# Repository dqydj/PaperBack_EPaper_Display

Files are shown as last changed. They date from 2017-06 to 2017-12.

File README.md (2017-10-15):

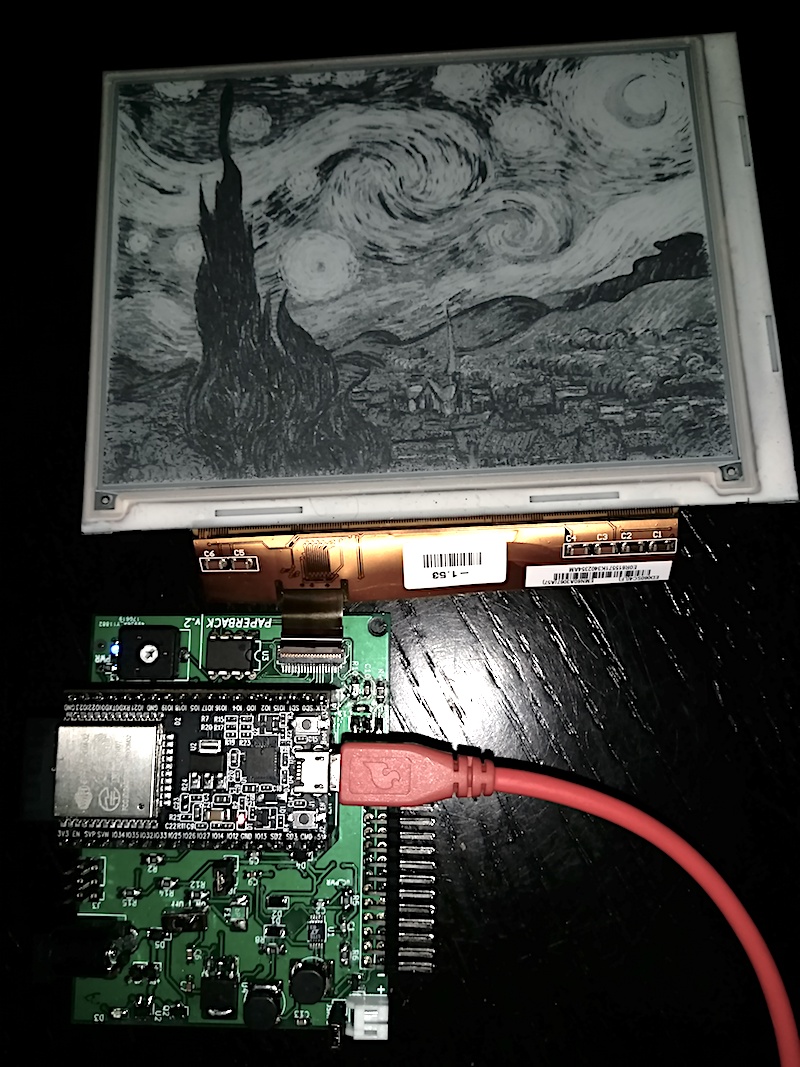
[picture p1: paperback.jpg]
Paperback Preview


# PaperBack EPaper Display

PaperBack is a modular, internet connected _*OR*_ VGA EPaper Display. It consists of a breakout board for a 39 pin ePaper display and an ESP32 in one mode. In the other, remove the ESP32 and attach a VGA Conversion board and use regular VGA input to drive the display!

PaperBack is an entry in the 2017 Hackaday Prize, you can see a more complete (and verbose!) [writeup here](https://hackaday.io/project/21607-paperback-desktop-e-paper-monitor).

## Hardware Overview

Currently, PaperBack works both driven by an ESP32 Development Board, or directly via VGA with the attached second PCB.

Hardware Overview:

* Espressif ESP32 Dev Board
* ED060SC4 // LB060S01 // LB060S04 6" ePaper Display
* 800x600 Resolution
* 16 Color (Greyscale) Support / 4-Bit Grey

## Software/Firmware Overview

Remember, choose one at a time! You can use the ESP32 breakout board with the ESP32 dev board, or remove the dev board and attach the VGA converter.

### VGA Driven

Unplug any ESP32 from the socket and attach both boards, then attach power (see below). When the board detects a signal it will start to refresh.

All firmware is in the /firmware_VGA/FPGA and /firmware_VGA/Microcontroller directories.

The user switches change color depth (read: shades of gray. 2 color is black & white.) and refresh speed:
Switch 3 (Furthest from Microcontroller)
Switch 2
Switch 1 (Closest to Microcontroller)

* On  On  On  - 16 color, ~10 seconds between frames
* On  On  Off - 16 color, ~5 seconds between frames
* On  Off On  - 4 color, ~10 seconds between frames
* On  Off Off - 4 color, ~5 seconds between frames
* Off On  On  - 4 color, ~1 frame per second
* Off On  Off - 2 color, ~10 seconds between frames
* Off Off On  - 2 color, ~5 seconds between frames
* Off Off Off - 2 color, ~1 frame per second

### ESP32 Dev Board Driven

Remove the second PCB if attached, then add the ESP32. There are *easy* ways to add power (there are pins exposed too, but these are easiest). Unless using Lithium and the DC adapter, only use one at a time!
* The board supports a single cell lithium ion battery with JST connector, and can charge it through the DC adapter hookup. Polarity is marker.
* The board can take a 2.1mm jack DC adapter, center positive. Aim for between 4.8 and 7 volts (don't create too much heat with something more).
* Disconnect all other supplies if you do this, but you can power it over USB from the ESP32. Connect the jumper labeled 'JP2' for this option.

Demos:

1. The Python utility `convert.py` in `/software/image_converter` automatically converts images which are compatible with Paperback's basic image demo. The image demo is in /firmware_ESP32/Paperback_Greyscale_Static_Image.

## Licensing and Other

* My main site: [DQYDJ](https://dqydj.com)
* Where available, all of the code is licensed as MIT.
* Where available, all of the hardware is licensed as MIT.
* If needed, other licenses will be quoted for individual parts.
* I would, of course, _love_ a link if you use any assets - but feel free to use everything as you wish.

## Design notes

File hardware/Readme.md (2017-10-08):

# Hardware Directory

Here you'll find the files you will need to reproduce Paperback.  There are two boards:

* *PaperBack_Display* The Display breakout board.  Can take an ESP32 Development Kit and run the display without the Video converter board.
* *PaperBack_Converter* The VGA conversion board.  Takes VGA, captures a frame, puts it in memory, then outputs to the ePaper screen.  _You can't run the ESP32 if you choose to dock board 2! Do not insert it!_.  

## Editing the Files

All files are from KiCad, although Gerbers are a universal format.  I've also included the PDF schematics as well if you'd like to spin a new PCB from scratch.

## License

MIT

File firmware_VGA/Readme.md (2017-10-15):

# MODE 2 - VGA

Remember, there are two ways to use PaperBack - either with only the first board and an ESP32 mounted, or with the VGA board attached. In this directory is the firmware to use the VGA monitor capabilities of PaperBack.

There are two devices you will need to program:
* Lattice MachXO LCMXO1200C FPGA
    * Look in the FPGA directory.
    * Code in there was programmed with Lattice Diamond: http://www.latticesemi.com/latticediamond
    * If you do not want to edit the code, a SVF file is included.
    * JTAG pins are clearly labeled on the bottom of the board, near the SRAM.
    * Power the board externally.
* Atmel ATMega328p
    * Look in the Microcontroller directory.
    * Code in there uses the Arduino IDE.
    * EDID code thanks to Rocky Hill: https://www.youtube.com/watch?v=UpAfaAhPGd4 // https://github.com/qbancoffee/edid_simulator
        * Follow his instructions to edit the I2C Library in Arduino
        * Set both to '128':
        * "BUFFER_LENGTH" in "arduino_install_folder/hardware/arduino/avr/libraries/Wire/src/Wire.h"
        * "TWI_BUFFER_LENGTH" in "arduino_install_folder/hardware/arduino/avr/libraries/Wire/src/utility/twi.h"
    * Install Tod E. Kurt's Soft I2C Master
        * https://github.com/todbot/SoftI2CMaster
    * The ICSP pins are next to the microcontroller - use a 3.3V programmer, or set the switch to 'disconnected' and power the board externally. The switch will turn off 

All code I wrote (the VHDL + a couple lines of C++) is Licensed MIT. 

Again: If you choose to drive PaperBack with the ESP32, DO NOT ATTACH THE SECOND BOARD. They _are_ modular, but I didn't add any electronics to switch between the two. If the second board is added, the ESP32 is connected to the exact same signal lines and you will short. Leave the ESP32 out of the socket.

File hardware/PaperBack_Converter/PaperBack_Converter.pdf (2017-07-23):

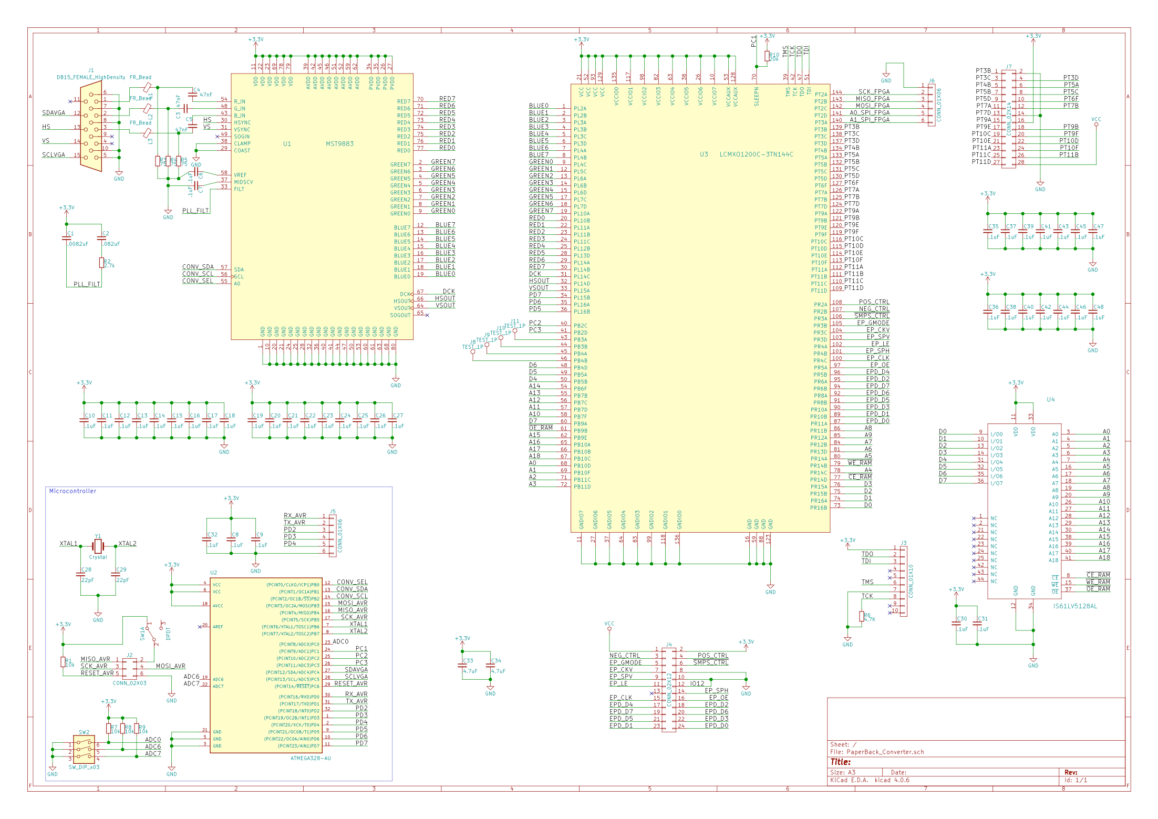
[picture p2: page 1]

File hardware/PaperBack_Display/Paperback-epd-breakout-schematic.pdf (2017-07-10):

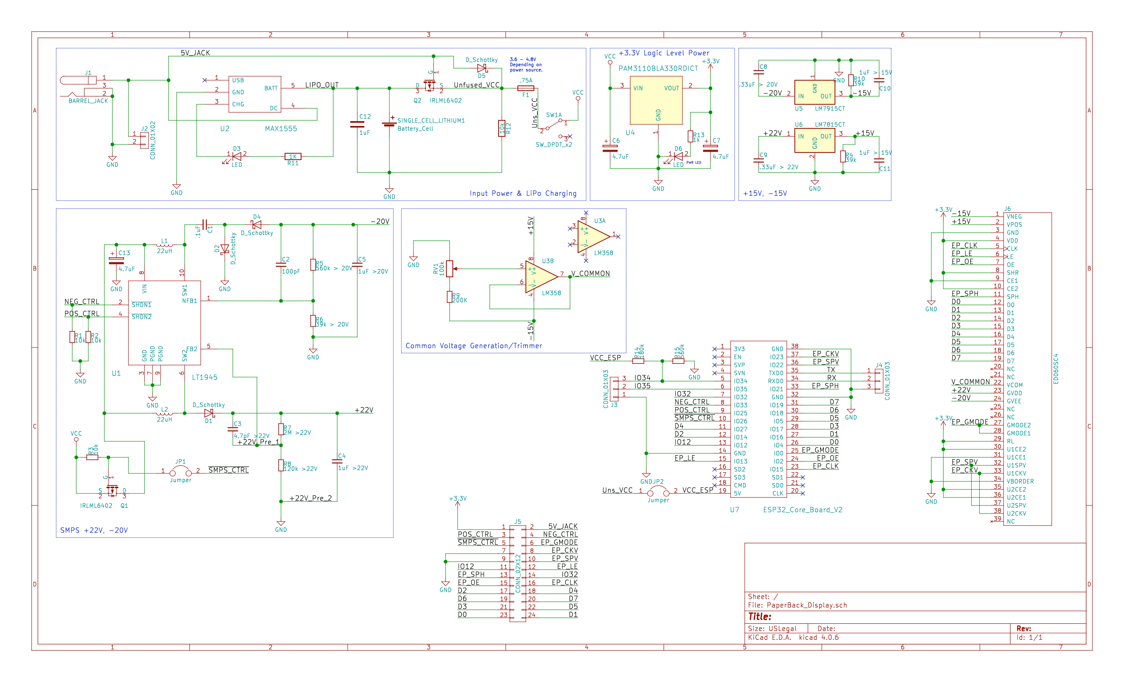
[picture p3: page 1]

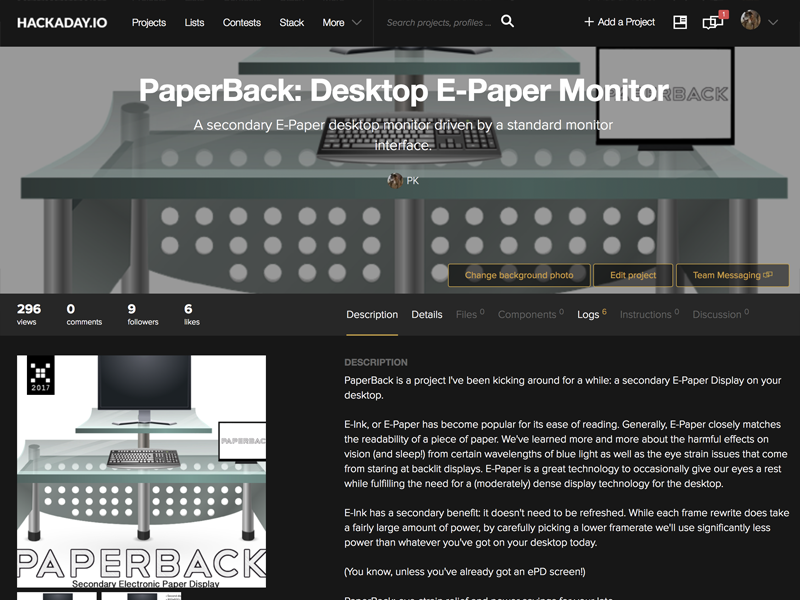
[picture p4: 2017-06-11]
server/photo_server/images/paperback.png

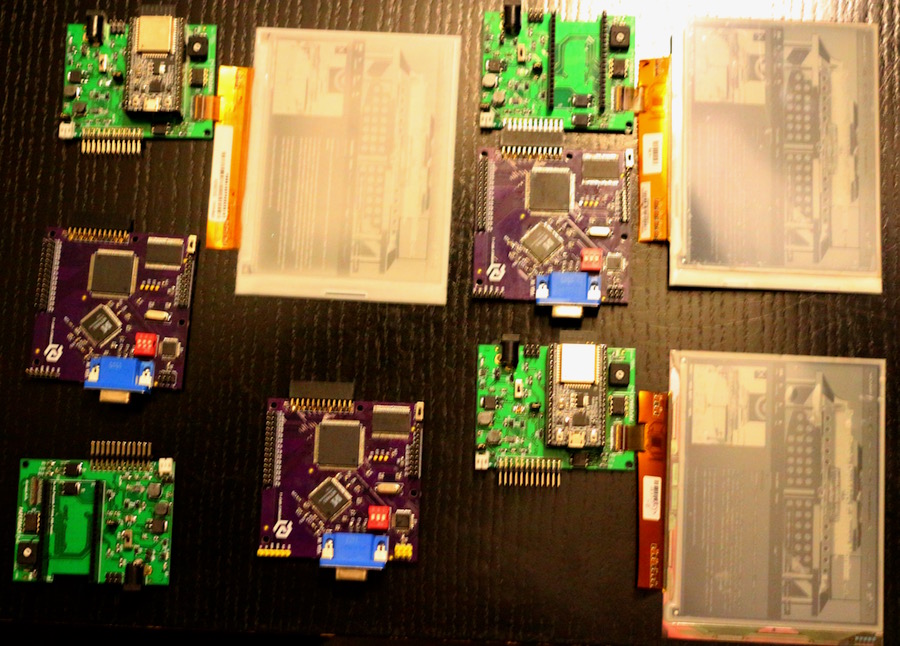
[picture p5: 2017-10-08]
hardware/PaperBack_Converter/family_pic_paperback.jpg

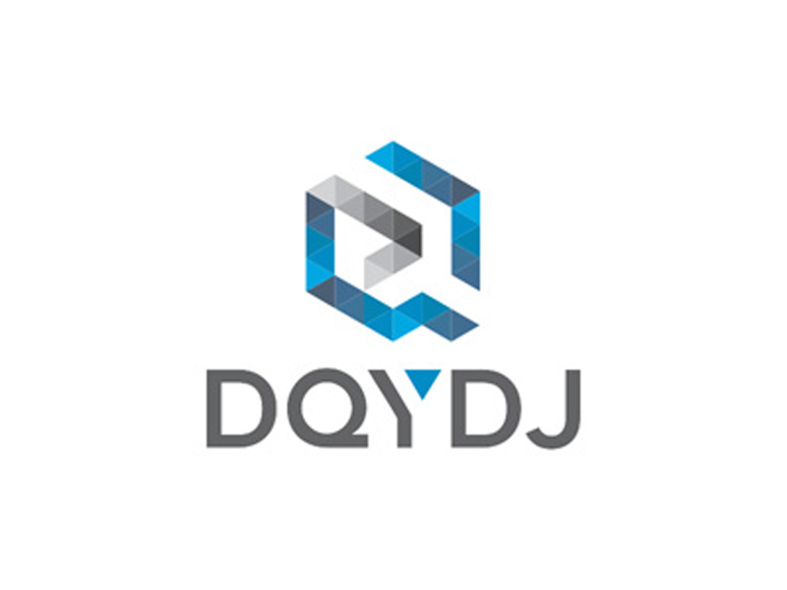
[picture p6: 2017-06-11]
server/photo_server/images/dqydj.bmp

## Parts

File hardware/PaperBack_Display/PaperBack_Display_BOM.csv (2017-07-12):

Reference | Value | Footprint
U2 | MAX1555 | TO_SOT_Packages_SMD:SOT-23-5_HandSoldering
D3 | LED | LEDs:LED_0805
R11 | 1K | Resistors_SMD:R_0805_HandSoldering
SINGLE_CELL_LITHIUM1 | Battery_Cell | PK_Footprints:JST_Right_Angle_02x01
C12 | 1uF | Capacitors_SMD:C_0603_HandSoldering
R12 | 10k | Resistors_SMD:R_0805_HandSoldering
F1 | .75A | Resistors_SMD:R_1210_HandSoldering
D5 | D_Schottky | PK_Footprints:D_SOD-123F
J2 | CONN_01X02 | Pin_Headers:Pin_Header_Straight_1x02_Pitch2.54mm
C6 | 4.7uF | Capacitors_SMD:C_0603_HandSoldering
C7 | 4.7uF | Capacitors_SMD:C_0603_HandSoldering
L1 | 22uH | PK_Footprints:DG6050C_Murata_Inductor
L2 | 22uH | PK_Footprints:DG6050C_Murata_Inductor
C3 | 4.7pF >22V | Capacitors_SMD:C_0603_HandSoldering
R8 | 120k >22V | Resistors_SMD:R_0805_HandSoldering
R7 | 2M >22V | Resistors_SMD:R_0805_HandSoldering
D1 | D_Schottky | PK_Footprints:D_SOD-123F
C4 | 1uF >22V | Capacitors_SMD:C_0603_HandSoldering
U5 | LM7915CT | TO_SOT_Packages_SMD:TO-252-3_TabPin2
C10 | 1uF > 15V | Capacitors_SMD:C_0603_HandSoldering
C8 | .33uF > 20V | Capacitors_SMD:C_0603_HandSoldering
U6 | LM7815CT | TO_SOT_Packages_SMD:TO-252-3_TabPin2
C9 | .33uF > 22V | Capacitors_SMD:C_0603_HandSoldering
C11 | 1uF > 15V | Capacitors_SMD:C_0603_HandSoldering
R3 | 10k | Resistors_SMD:R_0805_HandSoldering
R1 | 10k | Resistors_SMD:R_0805_HandSoldering
R2 | 10k | Resistors_SMD:R_0805_HandSoldering
U3 | LM358 | Housings_DIP:DIP-8_W7.62mm
R9 | 200K | Resistors_SMD:R_0805_HandSoldering
RV1 | 100k | PK_Footprints:CB10V_Trimmer
R10 | 39k | Resistors_SMD:R_0805_HandSoldering
R4 | 39k | Resistors_SMD:R_0805_HandSoldering
JP1 | Jumper | Pin_Headers:Pin_Header_Straight_1x02_Pitch2.54mm
J5 | CONN_02X12 | Pin_Headers:Pin_Header_Straight_2x12_Pitch2.54mm
U7 | ESP32_Core_Board_V2 | PK_Footprints:ESP32_Core_Board_v2
JP2 | Jumper | Pin_Headers:Pin_Header_Straight_1x02_Pitch2.54mm
J4 | CONN_01X03 | Pin_Headers:Pin_Header_Straight_1x03_Pitch2.54mm
U4 | PAM3110BLA330RDICT | TO_SOT_Packages_SMD:TO-252-3_TabPin2
J1 | BARREL_JACK | PK_Footprints:Switchcraft_5.5_2.1_Barrel_Jack
R13 | 1k | Resistors_SMD:R_0805_HandSoldering
D6 | LED | LEDs:LED_0805
C13 | 4.7uF | Capacitors_SMD:C_0603_HandSoldering
U1 | LT1945 | Housings_SSOP:MSOP-10_3x3mm_Pitch0.5mm
SW1 | SW_DPDT_x2 | Pin_Headers:Pin_Header_Straight_1x03_Pitch2.54mm
D4 | D_Schottky | PK_Footprints:D_SOD-123F
D2 | D_Schottky | PK_Footprints:D_SOD-123F
C2 | 100pF | Capacitors_SMD:C_0603_HandSoldering
R5 | 560k > 20V | Resistors_SMD:R_0805_HandSoldering
R6 | 39k > 20V | Resistors_SMD:R_0805_HandSoldering
C5 | 1uF >20V | Capacitors_SMD:C_0603_HandSoldering
C1 | .1uF | Capacitors_SMD:C_0603_HandSoldering
Q1 | IRLML6402 | TO_SOT_Packages_SMD:SOT-23
Q2 | IRLML6402 | TO_SOT_Packages_SMD:SOT-23
J6 | ED060SC4 | PK_Footprints:ED060SC4
J3 | CONN_01X03 | Pin_Headers:Pin_Header_Straight_1x03_Pitch2.54mm
R15 | 560k | Resistors_SMD:R_0805_HandSoldering
R14 | 180k | Resistors_SMD:R_0805_HandSoldering

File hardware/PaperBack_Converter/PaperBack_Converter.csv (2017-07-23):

Reference | Value | Footprint | Datasheet
J1 | DB15_FEMALE_HighDensity | PK_Footprints:VGA_HD15
L1 | FR_Bead | Inductors_SMD:L_0805_HandSoldering
L2 | FR_Bead | Inductors_SMD:L_0805_HandSoldering
L3 | FR_Bead | Inductors_SMD:L_0805_HandSoldering
C4 | 47nF | Capacitors_SMD:C_0603_HandSoldering
C3 | 47nF | Capacitors_SMD:C_0603_HandSoldering
C5 | 47nF | Capacitors_SMD:C_0603_HandSoldering
R3 | 75 | Resistors_SMD:R_0805_HandSoldering
R4 | 75 | Resistors_SMD:R_0805_HandSoldering
R5 | 75 | Resistors_SMD:R_0805_HandSoldering
C6 | .1uF | Capacitors_SMD:C_0603_HandSoldering
C7 | .1uF | Capacitors_SMD:C_0603_HandSoldering
C1 | .0082uF | Capacitors_SMD:C_0603_HandSoldering
C2 | .082uF | Capacitors_SMD:C_0603_HandSoldering
R2 | 2.7k | Resistors_SMD:R_0805_HandSoldering
U2 | ATMEGA328-AU | Housings_QFP:TQFP-32_7x7mm_Pitch0.8mm
J2 | CONN_02X03 | Pin_Headers:Pin_Header_Straight_2x03_Pitch2.54mm
R1 | 10k | Resistors_SMD:R_0805_HandSoldering
U4 | IS61LV5128AL | PK_Footprints:TSOP_II_44_0.8mm
J3 | CONN_01X10 | Pin_Headers:Pin_Header_Straight_1x10_Pitch2.54mm
R6 | 4.7K | Resistors_SMD:R_0805_HandSoldering
J4 | CONN_02X12 | Pin_Headers:Pin_Header_Straight_2x12_Pitch2.54mm
C8 | .1uF | Capacitors_SMD:C_0603_HandSoldering
C9 | .1uF | Capacitors_SMD:C_0603_HandSoldering
J5 | CONN_01X06 | Pin_Headers:Pin_Header_Straight_1x06_Pitch2.54mm
C11 | .1uF | Capacitors_SMD:C_0603_HandSoldering
C12 | .1uF | Capacitors_SMD:C_0603_HandSoldering
C13 | .1uF | Capacitors_SMD:C_0603_HandSoldering
C14 | .1uF | Capacitors_SMD:C_0603_HandSoldering
C15 | .1uF | Capacitors_SMD:C_0603_HandSoldering
C16 | .1uF | Capacitors_SMD:C_0603_HandSoldering
C17 | .1uF | Capacitors_SMD:C_0603_HandSoldering
C18 | .1uF | Capacitors_SMD:C_0603_HandSoldering
C10 | .1uF | Capacitors_SMD:C_0603_HandSoldering
C20 | .1uF | Capacitors_SMD:C_0603_HandSoldering
C21 | .1uF | Capacitors_SMD:C_0603_HandSoldering
C22 | .1uF | Capacitors_SMD:C_0603_HandSoldering
C23 | .1uF | Capacitors_SMD:C_0603_HandSoldering
C24 | .1uF | Capacitors_SMD:C_0603_HandSoldering
C25 | .1uF | Capacitors_SMD:C_0603_HandSoldering
C26 | .1uF | Capacitors_SMD:C_0603_HandSoldering
C27 | .1uF | Capacitors_SMD:C_0603_HandSoldering
C19 | .1uF | Capacitors_SMD:C_0603_HandSoldering
C30 | .1uF | Capacitors_SMD:C_0603_HandSoldering
C31 | .1uF | Capacitors_SMD:C_0603_HandSoldering
Y1 | Crystal 7.3728 MHz | Crystals:Crystal_SMD_HC49-SD
C28 | 22pF | Capacitors_SMD:C_0603_HandSoldering
C29 | 22pF | Capacitors_SMD:C_0603_HandSoldering
C32 | .1uF | Capacitors_SMD:C_0603_HandSoldering
SW1 | DPDT | Pin_Headers:Pin_Header_Straight_1x03_Pitch2.54mm
C33 | 4.7uF | Capacitors_SMD:C_0603_HandSoldering
C34 | 4.7uF | Capacitors_SMD:C_0603_HandSoldering
J6 | CONN_01X06 | Pin_Headers:Pin_Header_Straight_1x06_Pitch2.54mm
J7 | CONN_02X14 | Socket_Strips:Socket_Strip_Straight_2x14_Pitch2.54mm
C37 | .1uF | Capacitors_SMD:C_0603_HandSoldering
C39 | .1uF | Capacitors_SMD:C_0603_HandSoldering
C41 | .1uF | Capacitors_SMD:C_0603_HandSoldering
C43 | .1uF | Capacitors_SMD:C_0603_HandSoldering
C45 | .1uF | Capacitors_SMD:C_0603_HandSoldering
C47 | .1uF | Capacitors_SMD:C_0603_HandSoldering
C35 | .1uF | Capacitors_SMD:C_0603_HandSoldering
C38 | .1uF | Capacitors_SMD:C_0603_HandSoldering
C40 | .1uF | Capacitors_SMD:C_0603_HandSoldering
C42 | .1uF | Capacitors_SMD:C_0603_HandSoldering
C44 | .1uF | Capacitors_SMD:C_0603_HandSoldering
C46 | .1uF | Capacitors_SMD:C_0603_HandSoldering
C48 | .1uF | Capacitors_SMD:C_0603_HandSoldering
C36 | .1uF | Capacitors_SMD:C_0603_HandSoldering
SW2 | SW_DIP_x03 | Buttons_Switches_THT:SW_DIP_x3_W7.62mm_Slide
R7 | 10k | Resistors_SMD:R_0805_HandSoldering
R8 | 10k | Resistors_SMD:R_0805_HandSoldering
R9 | 10k | Resistors_SMD:R_0805_HandSoldering
J8 | TEST_1P | Measurement_Points:Measurement_Point_Round-SMD-Pad_Small
J9 | TEST_1P | Measurement_Points:Measurement_Point_Round-SMD-Pad_Small
J10 | TEST_1P | Measurement_Points:Measurement_Point_Round-SMD-Pad_Small
J11 | TEST_1P | Measurement_Points:Measurement_Point_Round-SMD-Pad_Small
U3 | LCMXO1200C-3TN144C | PK_Footprints:TQFP-144_20x20mm_Pitch0.5mm
R10 | 20k | Resistors_SMD:R_0805_HandSoldering
U1 | MST9883 | Housings_QFP:TQFP-80_12x12mm_Pitch0.5mm

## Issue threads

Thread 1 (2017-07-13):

Eink issue?

berkutta, 2017-07-13:
Do you have the issue too, that sometimes just some horizontal lines get set instead of all? (When writing all to black).

And have you any idea if that is normal, that there is quite a big white space between every horizontal line?

dqydj, 2017-07-14:
Yes, I do - but _only_ with one ESP that I believe I shorted out (the one in the picture).  The two I used on the early prototypes have issues now - one won't drive the screen at all and the second causes vertical line skipping.  I got another ESP32 today (after I knew this board spin was working) and it drives the full screen properly.

I'd suggest popping a logic analyzer on the data pins; perhaps some of the LSBs are shorted out, which could cause that sort of effect.  Let me know if that's what it was.

Closed 2017-07-14.

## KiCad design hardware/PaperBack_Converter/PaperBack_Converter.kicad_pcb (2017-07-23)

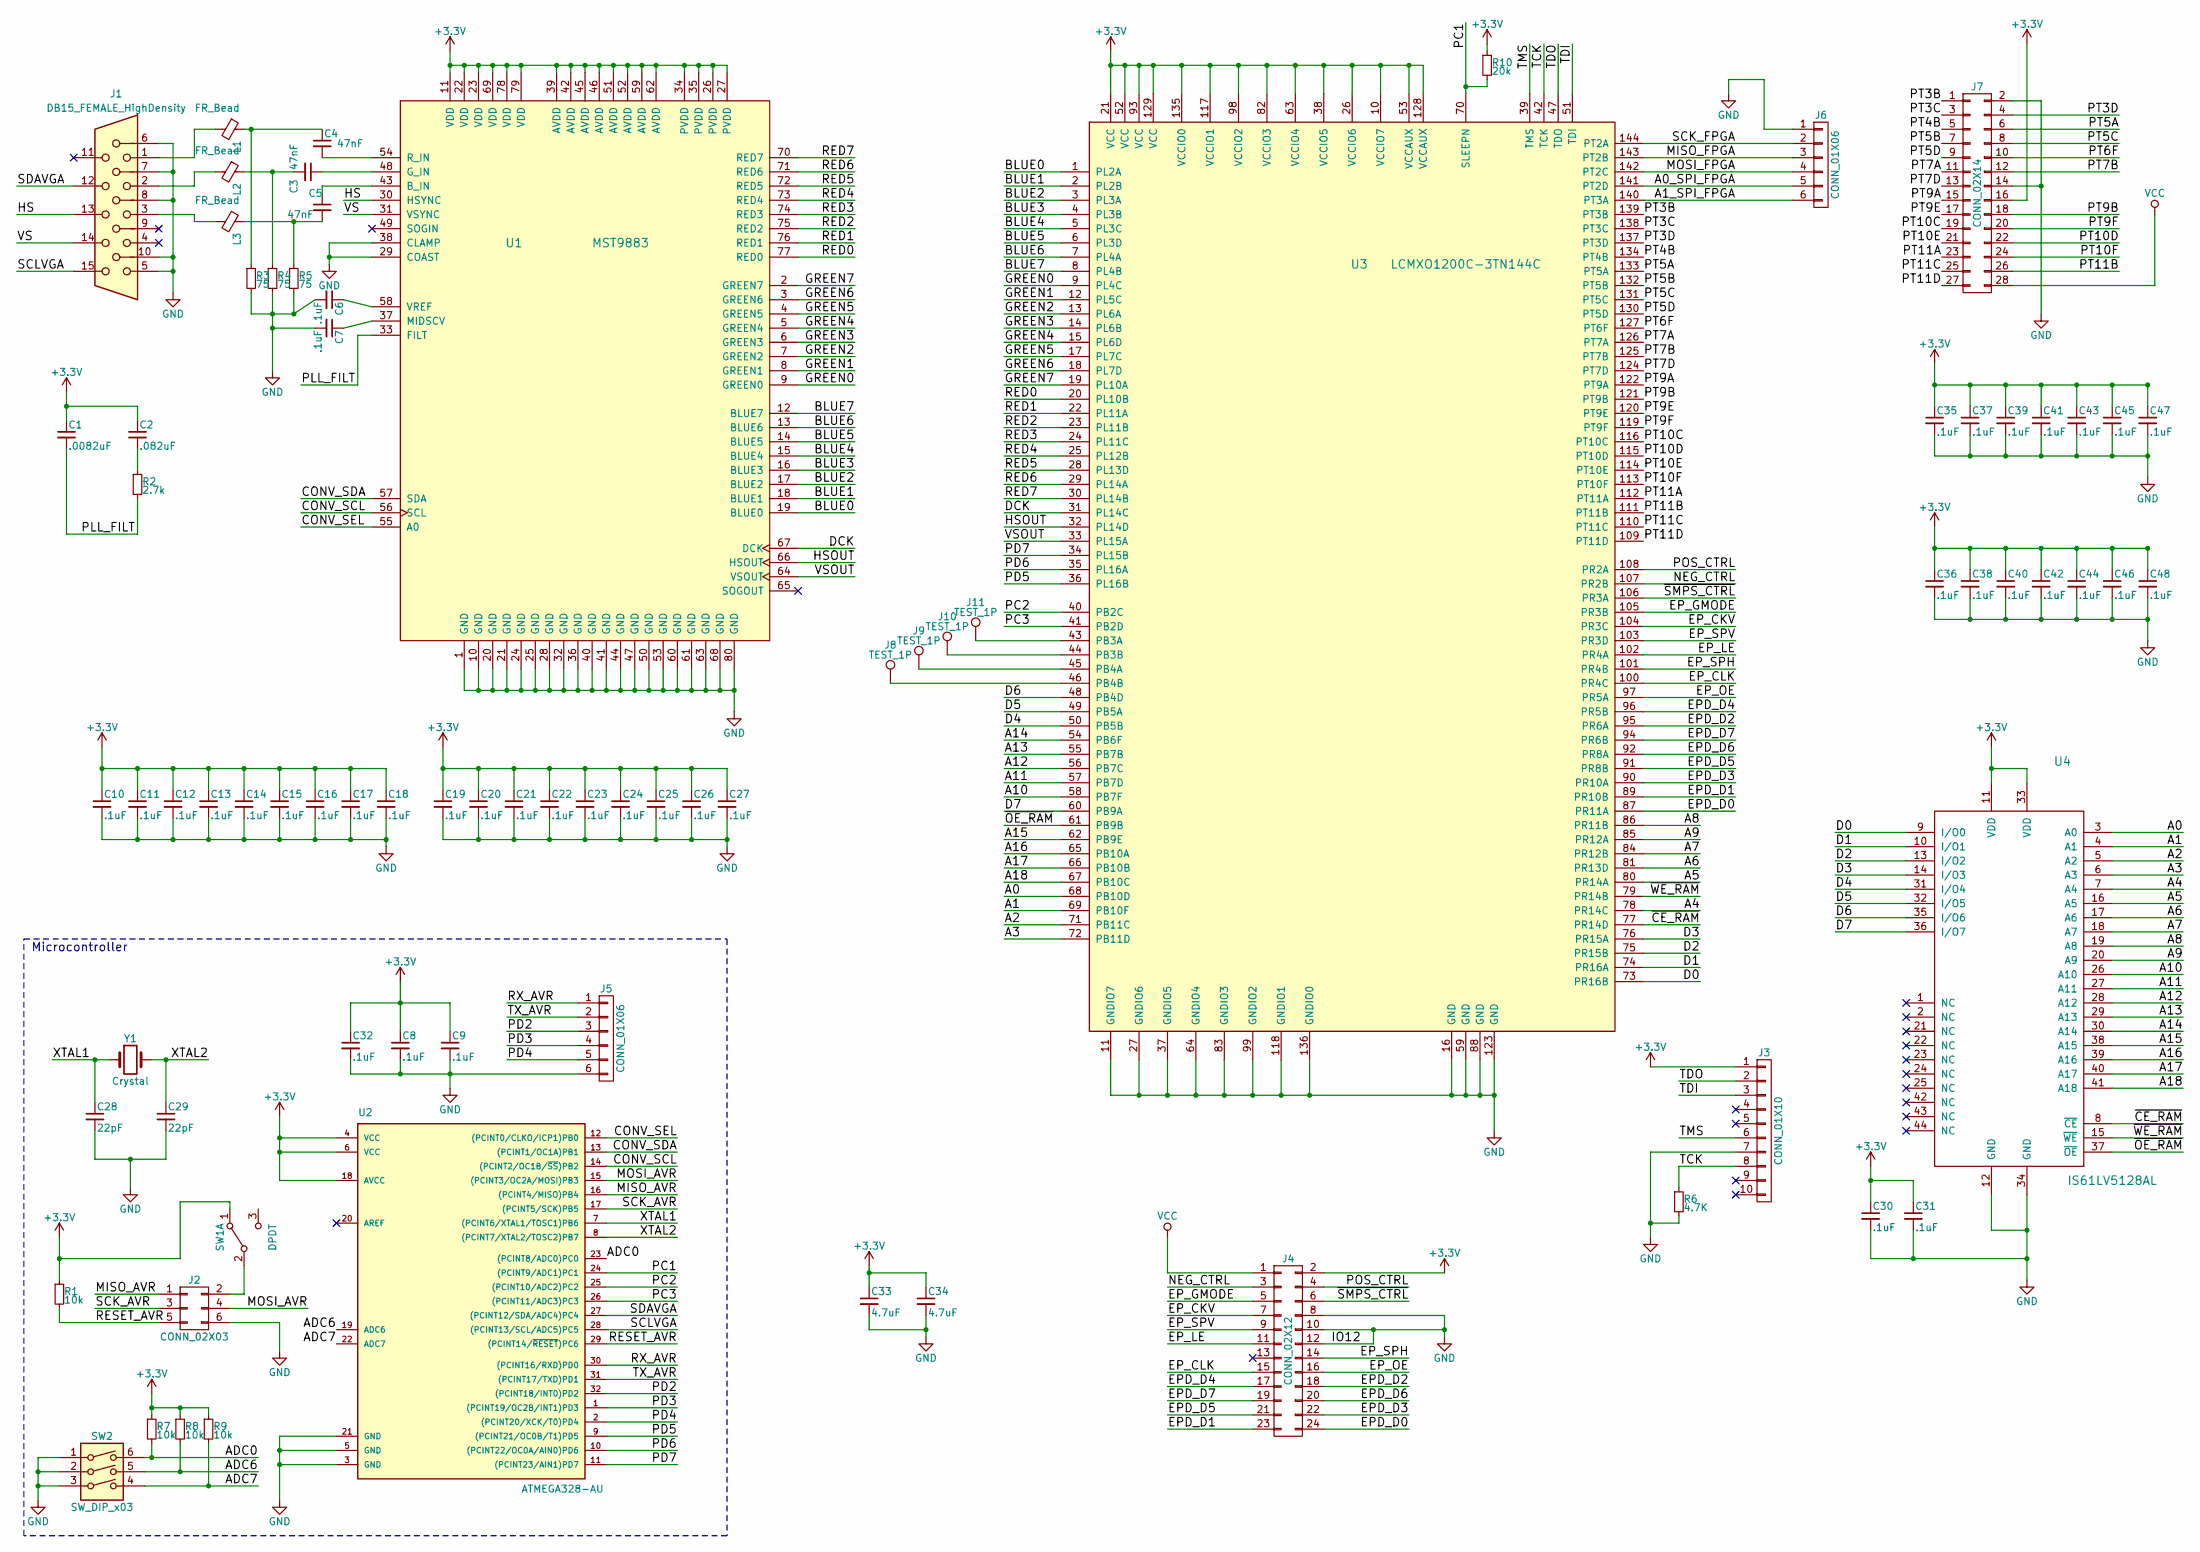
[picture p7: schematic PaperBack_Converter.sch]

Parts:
C1: .0082uF; C_0603_HandSoldering
C2: .082uF; C_0603_HandSoldering
C3, C4, C5: 47nF; C_0603_HandSoldering
C6, C7, C8, C9, C10, C11, C12, C13, C14, C15, C16, C17, C18, C19, C20, C21, C22, C23, C24, C25, C26, C27, C30, C31, C32, C35, C36, C37, C38, C39, C40, C41, C42, C43, C44, C45, C46, C47, C48: .1uF; C_0603_HandSoldering
C28, C29: 22pF; C_0603_HandSoldering
C33, C34: 4.7uF; C_0603_HandSoldering
J1: DB15_FEMALE_HighDensity; VGA_HD15
J2: CONN_02X03; Pin_Header_Straight_2x03_Pitch2.54mm
J3: CONN_01X10; Pin_Header_Straight_1x10_Pitch2.54mm
J4: CONN_02X12; Pin_Header_Straight_2x12_Pitch2.54mm
J5, J6: CONN_01X06; Pin_Header_Straight_1x06_Pitch2.54mm
J7: CONN_02X14; Socket_Strip_Straight_2x14_Pitch2.54mm
J8, J9, J10, J11: TEST_1P; Measurement_Point_Round-SMD-Pad_Small
L1, L2, L3: FR_Bead; L_0805_HandSoldering
R1, R7, R8, R9: 10k; R_0805_HandSoldering
R2: 2.7k; R_0805_HandSoldering
R3, R4, R5: 75; R_0805_HandSoldering
R6: 4.7K; R_0805_HandSoldering
R10: 20k; R_0805_HandSoldering
SW1: DPDT; Pin_Header_Straight_1x03_Pitch2.54mm
SW2: SW_DIP_x03; SW_DIP_x3_W7.62mm_Slide
U1: MST9883; TQFP-80_14x14mm_Pitch0.65mm
U2: ATMEGA328-AU; TQFP-32_7x7mm_Pitch0.8mm
U3: LCMXO1200C-3TN144C; TQFP-144_20x20mm_Pitch0.5mm
U4: IS61LV5128AL; TSOP_II_44_0.8mm
Y1: Crystal; Crystal_SMD_HC49-SD

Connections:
+3V3: C1.1, C2.1, C8.1, C9.1, C10.1, C11.1, C12.1, C13.1, C14.1, C15.1, C16.1, C17.1, C18.1, C19.1, C20.1, C21.1, C22.1, C23.1, C24.1, C25.1, C26.1, C27.1, C30.1, C31.1, C32.1, C33.1, C34.1, C35.1, C36.1, C37.1, C38.1, C39.1, C40.1, C41.1, C42.1, C43.1, C44.1, C45.1, C46.1, C47.1, C48.1, J3.1, J4.2, J7.16, R1.1, R7.1, R8.1, R9.1, R10.1, SW1.1 (A), U1.11 (VDD), U1.22 (VDD), U1.23 (VDD), U1.26 (PVDD), U1.27 (PVDD), U1.34 (PVDD), U1.35 (PVDD), U1.39 (AVDD), U1.42 (AVDD), U1.45 (AVDD), U1.46 (AVDD), U1.51 (AVDD), U1.52 (AVDD), U1.59 (AVDD), U1.62 (AVDD), U1.69 (VDD), U1.78 (VDD), U1.79 (VDD), U2.4 (VCC), U2.6 (VCC), U2.18 (AVCC), U3.10 (VCCIO7), U3.21 (VCC), U3.26 (VCCIO6), U3.38 (VCCIO5), U3.52 (VCC), U3.53 (VCCAUX), U3.63 (VCCIO4), U3.82 (VCCIO3), U3.93 (VCC), U3.98 (VCCIO2), U3.117 (VCCIO1), U3.128 (VCCAUX), U3.129 (VCC), U3.135 (VCCIO0), U4.11 (VDD), U4.33 (VDD)
/A0: U3.68 (PB10D), U4.3 (A0)
/A0_SPI_FPGA: J6.5, U3.141 (PT2D)
/A1: U3.69 (PB10F), U4.4 (A1)
/A1_SPI_FPGA: J6.6, U3.140 (PT3A)
/A2: U3.71 (PB11C), U4.5 (A2)
/A3: U3.72 (PB11D), U4.6 (A3)
/A4: U3.78 (PR14C), U4.7 (A4)
/A5: U3.80 (PR14A), U4.16 (A5)
/A6: U3.81 (PR13D), U4.17 (A6)
/A7: U3.84 (PR12B), U4.18 (A7)
/A8: U3.86 (PR11B), U4.19 (A8)
/A9: U3.85 (PR12A), U4.20 (A9)
/A10: U3.58 (PB7F), U4.26 (A10)
/A11: U3.57 (PB7D), U4.27 (A11)
/A12: U3.56 (PB7C), U4.28 (A12)
/A13: U3.55 (PB7B), U4.29 (A13)
/A14: U3.54 (PB6F), U4.30 (A14)
/A15: U3.62 (PB9E), U4.38 (A15)
/A16: U3.65 (PB10A), U4.39 (A16)
/A17: U3.66 (PB10B), U4.40 (A17)
/A18: U3.67 (PB10C), U4.41 (A18)
/ADC0: R7.2, SW2.6, U2.23 ((PCINT8/ADC0)PC0)
/ADC6: R8.2, SW2.5, U2.19 (ADC6)
/ADC7: R9.2, SW2.4, U2.22 (ADC7)
/BLUE0: U1.19 (BLUE0), U3.1 (PL2A)
/BLUE1: U1.18 (BLUE1), U3.2 (PL2B)
/BLUE2: U1.17 (BLUE2), U3.3 (PL3A)
/BLUE3: U1.16 (BLUE3), U3.4 (PL3B)
/BLUE4: U1.15 (BLUE4), U3.5 (PL3C)
/BLUE5: U1.14 (BLUE5), U3.6 (PL3D)
/BLUE6: U1.13 (BLUE6), U3.7 (PL4A)
/BLUE7: U1.12 (BLUE7), U3.8 (PL4B)
/CONV_SCL: U1.56 (SCL), U2.14 ((PCINT2/OC1B/~SS~)PB2)
/CONV_SDA: U1.57 (SDA), U2.13 ((PCINT1/OC1A)PB1)
/CONV_SEL: U1.55 (A0), U2.12 ((PCINT0/CLKO/ICP1)PB0)
/D0: U3.73 (PR16B), U4.9 (I/O0)
/D1: U3.74 (PR16A), U4.10 (I/O1)
/D2: U3.75 (PR15B), U4.13 (I/O2)
/D3: U3.76 (PR15A), U4.14 (I/O3)
/D4: U3.50 (PB5B), U4.31 (I/O4)
/D5: U3.49 (PB5A), U4.32 (I/O5)
/D6: U3.48 (PB4D), U4.35 (I/O6)
/D7: U3.60 (PB9A), U4.36 (I/O7)
/DCK: U1.67 (DCK), U3.31 (PL14C)
/EPD_D0: J4.24, U3.87 (PR11A)
/EPD_D1: J4.23, U3.89 (PR10B)
/EPD_D2: J4.18, U3.95 (PR6A)
/EPD_D3: J4.22, U3.90 (PR10A)
/EPD_D4: J4.17, U3.96 (PR5B)
/EPD_D5: J4.21, U3.91 (PR8B)
/EPD_D6: J4.20, U3.92 (PR8A)
/EPD_D7: J4.19, U3.94 (PR6B)
/EP_CKV: J4.7, U3.104 (PR3C)
/EP_CLK: J4.15, U3.100 (PR4C)
/EP_GMODE: J4.5, U3.105 (PR3B)
/EP_LE: J4.11, U3.102 (PR4A)
/EP_OE: J4.16, U3.97 (PR5A)
/EP_SPH: J4.14, U3.101 (PR4B)
/EP_SPV: J4.9, U3.103 (PR3D)
/GREEN0: U1.9 (GREEN0), U3.9 (PL4C)
/GREEN1: U1.8 (GREEN1), U3.12 (PL5C)
/GREEN2: U1.7 (GREEN2), U3.13 (PL6A)
/GREEN3: U1.6 (GREEN3), U3.14 (PL6B)
/GREEN4: U1.5 (GREEN4), U3.15 (PL6D)
/GREEN5: U1.4 (GREEN5), U3.17 (PL7C)
/GREEN6: U1.3 (GREEN6), U3.18 (PL7D)
/GREEN7: U1.2 (GREEN7), U3.19 (PL10A)
/HS: J1.13, U1.30 (HSYNC)
/HSOUT: U1.66 (HSOUT), U3.32 (PL14D)
/MISO_AVR: J2.1, U2.16 ((PCINT4/MISO)PB4)
/MISO_FPGA: J6.3, U3.143 (PT2B)
/MOSI_AVR: J2.4, U2.15 ((PCINT3/OC2A/MOSI)PB3)
/MOSI_FPGA: J6.4, U3.142 (PT2C)
/NEG_CTRL: J4.3, U3.107 (PR2B)
/PC1: R10.2, U2.24 ((PCINT9/ADC1)PC1), U3.70 (SLEEPN)
/PC2: U2.25 ((PCINT10/ADC2)PC2), U3.40 (PB2C)
/PC3: U2.26 ((PCINT11/ADC3)PC3), U3.41 (PB2D)
/PD2: J5.3, U2.32 ((PCINT18/INT0)PD2)
/PD3: J5.4, U2.1 ((PCINT19/OC2B/INT1)PD3)
/PD4: J5.5, U2.2 ((PCINT20/XCK/T0)PD4)
/PD5: U2.9 ((PCINT21/OC0B/T1)PD5), U3.36 (PL16B)
/PD6: U2.10 ((PCINT22/OC0A/AIN0)PD6), U3.35 (PL16A)
/PD7: U2.11 ((PCINT23/AIN1)PD7), U3.34 (PL15B)
/PLL_FILT: C1.2, R2.2, U1.33 (FILT)
/POS_CTRL: J4.4, U3.108 (PR2A)
/PT3B: J7.1, U3.139 (PT3B)
/PT3C: J7.3, U3.138 (PT3C)
/PT3D: J7.4, U3.137 (PT3D)
/PT4B: J7.5, U3.134 (PT4B)
/PT5A: J7.6, U3.133 (PT5A)
/PT5B: J7.7, U3.132 (PT5B)
/PT5C: J7.8, U3.131 (PT5C)
/PT5D: J7.9, U3.130 (PT5D)
/PT6F: J7.10, U3.127 (PT6F)
/PT7A: J7.11, U3.126 (PT7A)
/PT7B: J7.12, U3.125 (PT7B)
/PT7D: J7.13, U3.124 (PT7D)
/PT9A: J7.15, U3.122 (PT9A)
/PT9B: J7.18, U3.121 (PT9B)
/PT9E: J7.17, U3.120 (PT9E)
/PT9F: J7.20, U3.119 (PT9F)
/PT10C: J7.19, U3.116 (PT10C)
/PT10D: J7.22, U3.115 (PT10D)
/PT10E: J7.21, U3.114 (PT10E)
/PT10F: J7.24, U3.113 (PT10F)
/PT11A: J7.23, U3.112 (PT11A)
/PT11B: J7.26, U3.111 (PT11B)
/PT11C: J7.25, U3.110 (PT11C)
/PT11D: J7.27, U3.109 (PT11D)
/RED0: U1.77 (RED0), U3.20 (PL10B)
/RED1: U1.76 (RED1), U3.22 (PL11A)
/RED2: U1.75 (RED2), U3.23 (PL11B)
/RED3: U1.74 (RED3), U3.24 (PL11C)
/RED4: U1.73 (RED4), U3.25 (PL12B)
/RED5: U1.72 (RED5), U3.28 (PL13D)
/RED6: U1.71 (RED6), U3.29 (PL14A)
/RED7: U1.70 (RED7), U3.30 (PL14B)
/RESET_AVR: J2.5, R1.2, U2.29 ((PCINT14/~RESET~)PC6)
/RX_AVR: J5.1, U2.30 ((PCINT16/RXD)PD0)
/SCK_AVR: J2.3, U2.17 ((PCINT5/SCK)PB5)
/SCK_FPGA: J6.2, U3.144 (PT2A)
/SCLVGA: J1.15, U2.28 ((PCINT13/SCL/ADC5)PC5)
/SDAVGA: J1.12, U2.27 ((PCINT12/SDA/ADC4)PC4)
/TCK: J3.8, R6.1, U3.42 (TCK)
/TDI: J3.3, U3.51 (TDI)
/TDO: J3.2, U3.47 (TDO)
/TMS: J3.6, U3.39 (TMS)
/TX_AVR: J5.2, U2.31 ((PCINT17/TXD)PD1)
/VS: J1.14, U1.31 (VSYNC)
/VSOUT: U1.64 (VSOUT), U3.33 (PL15A)
/XTAL1: C28.1, U2.7 ((PCINT6/XTAL1/TOSC1)PB6), Y1.1
/XTAL2: C29.1, U2.8 ((PCINT7/XTAL2/TOSC2)PB7), Y1.2
/~CE_RAM: U3.77 (PR14D), U4.8 (~CE)
/~OE_RAM: U3.61 (PB9B), U4.37 (~OE)
/~SMPS_CTRL: J4.6, U3.106 (PR3A)
/~WE_RAM: U3.79 (PR14B), U4.15 (~WE)
GND: C6.2, C7.2, C8.2, C9.2, C10.2, C11.2, C12.2, C13.2, C14.2, C15.2, C16.2, C17.2, C18.2, C19.2, C20.2, C21.2, C22.2, C23.2, C24.2, C25.2, C26.2, C27.2, C28.2, C29.2, C30.2, C31.2, C32.2, C33.2, C34.2, C35.2, C36.2, C37.2, C38.2, C39.2, C40.2, C41.2, C42.2, C43.2, C44.2, C45.2, C46.2, C47.2, C48.2, J1.5, J1.6, J1.7, J1.8, J1.10, J2.6, J3.7, J4.8, J4.10, J4.12, J5.6, J6.1, J7.2, J7.14, R3.2, R4.2, R5.2, R6.2, SW2.1, SW2.2, SW2.3, U1.1 (GND), U1.10 (GND), U1.20 (GND), U1.21 (GND), U1.24 (GND), U1.25 (GND), U1.28 (GND), U1.29 (COAST), U1.32 (GND), U1.36 (GND), U1.38 (CLAMP), U1.40 (GND), U1.41 (GND), U1.44 (GND), U1.47 (GND), U1.50 (GND), U1.53 (GND), U1.60 (GND), U1.61 (GND), U1.63 (GND), U1.68 (GND), U1.80 (GND), U2.3 (GND), U2.5 (GND), U2.21 (GND), U3.11 (GNDIO7), U3.16 (GND), U3.27 (GNDIO6), U3.37 (GNDIO5), U3.59 (GND), U3.64 (GNDIO4), U3.83 (GNDIO3), U3.88 (GND), U3.99 (GNDIO2), U3.118 (GNDIO1), U3.123 (GND), U3.136 (GNDIO0), U4.12 (GND), U4.34 (GND)
unnamed: C2.2, R2.1
unnamed: C3.1, U1.48 (G_IN)
unnamed: C3.2, L2.1, R4.1
unnamed: C4.1, L1.1, R3.1
unnamed: C4.2, U1.54 (R_IN)
unnamed: C5.1, U1.43 (B_IN)
unnamed: C5.2, L3.1, R5.1
unnamed: C6.1, U1.58 (VREF)
unnamed: C7.1, U1.37 (MIDSCV)
unnamed: J1.1, L1.2
unnamed: J1.2, L2.2
unnamed: J1.3, L3.2
unnamed: J2.2, SW1.2 (B)
unnamed: J8.1, U3.46 (PB4B)
unnamed: J9.1, U3.45 (PB4A)
unnamed: J10.1, U3.44 (PB3B)
unnamed: J11.1, U3.43 (PB3A)
VCC: J4.1, J7.28

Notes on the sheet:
Microcontroller

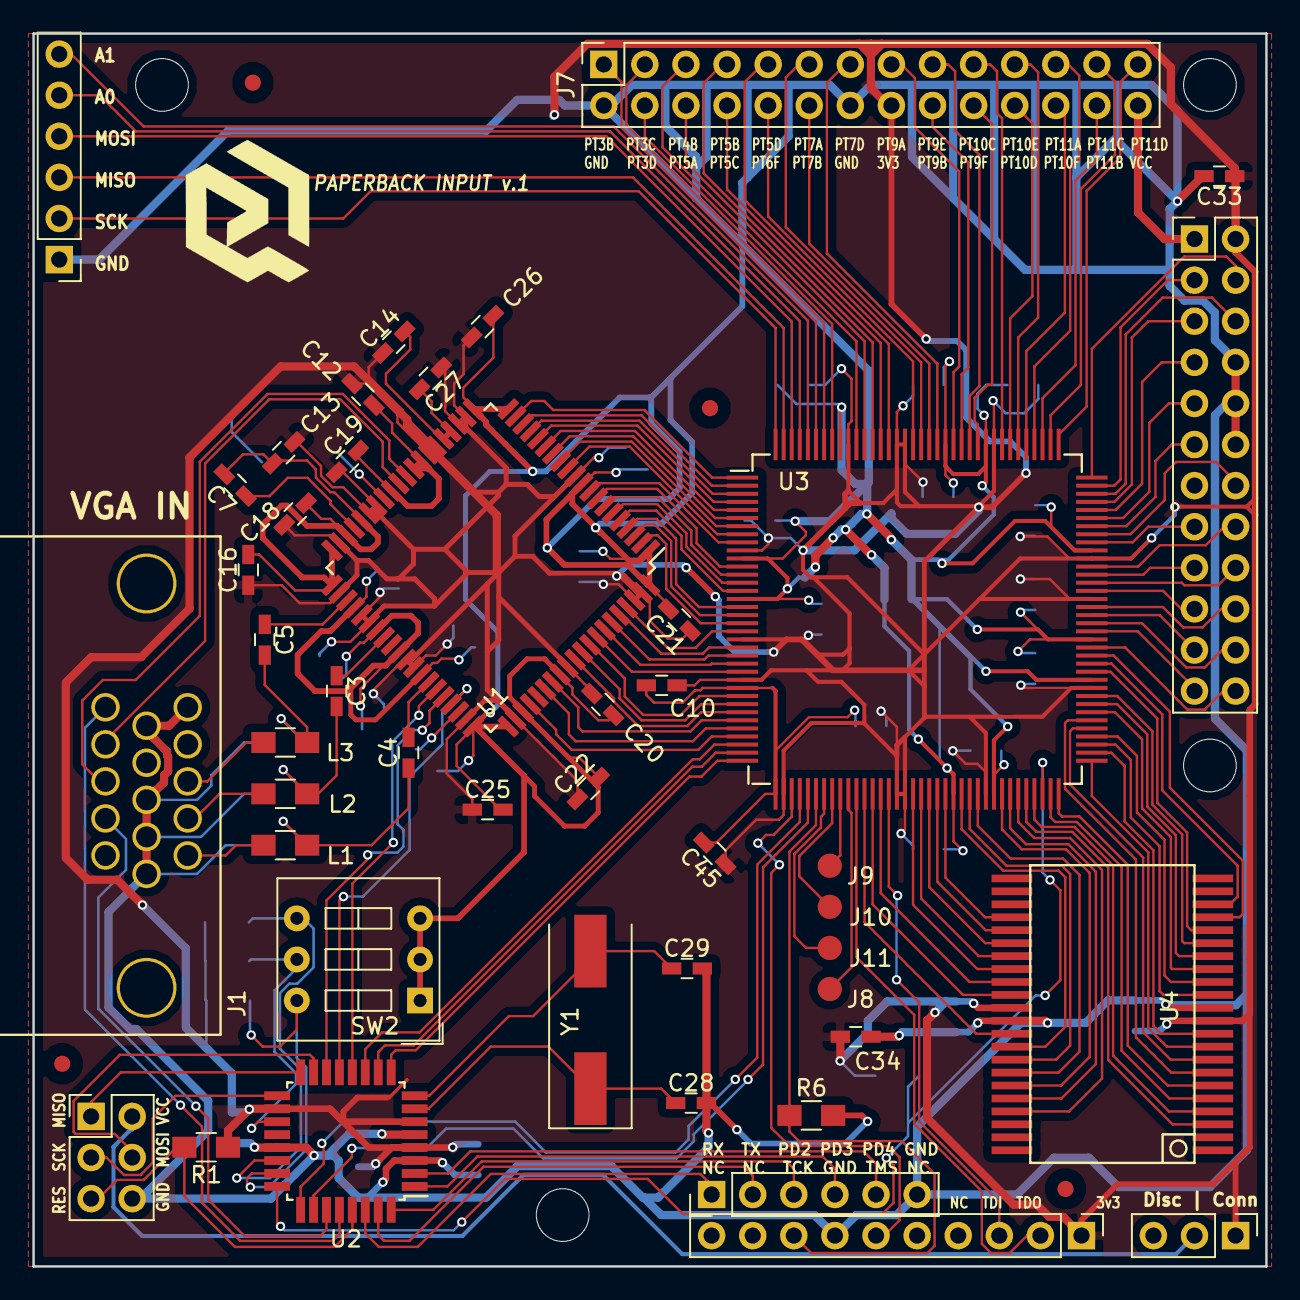
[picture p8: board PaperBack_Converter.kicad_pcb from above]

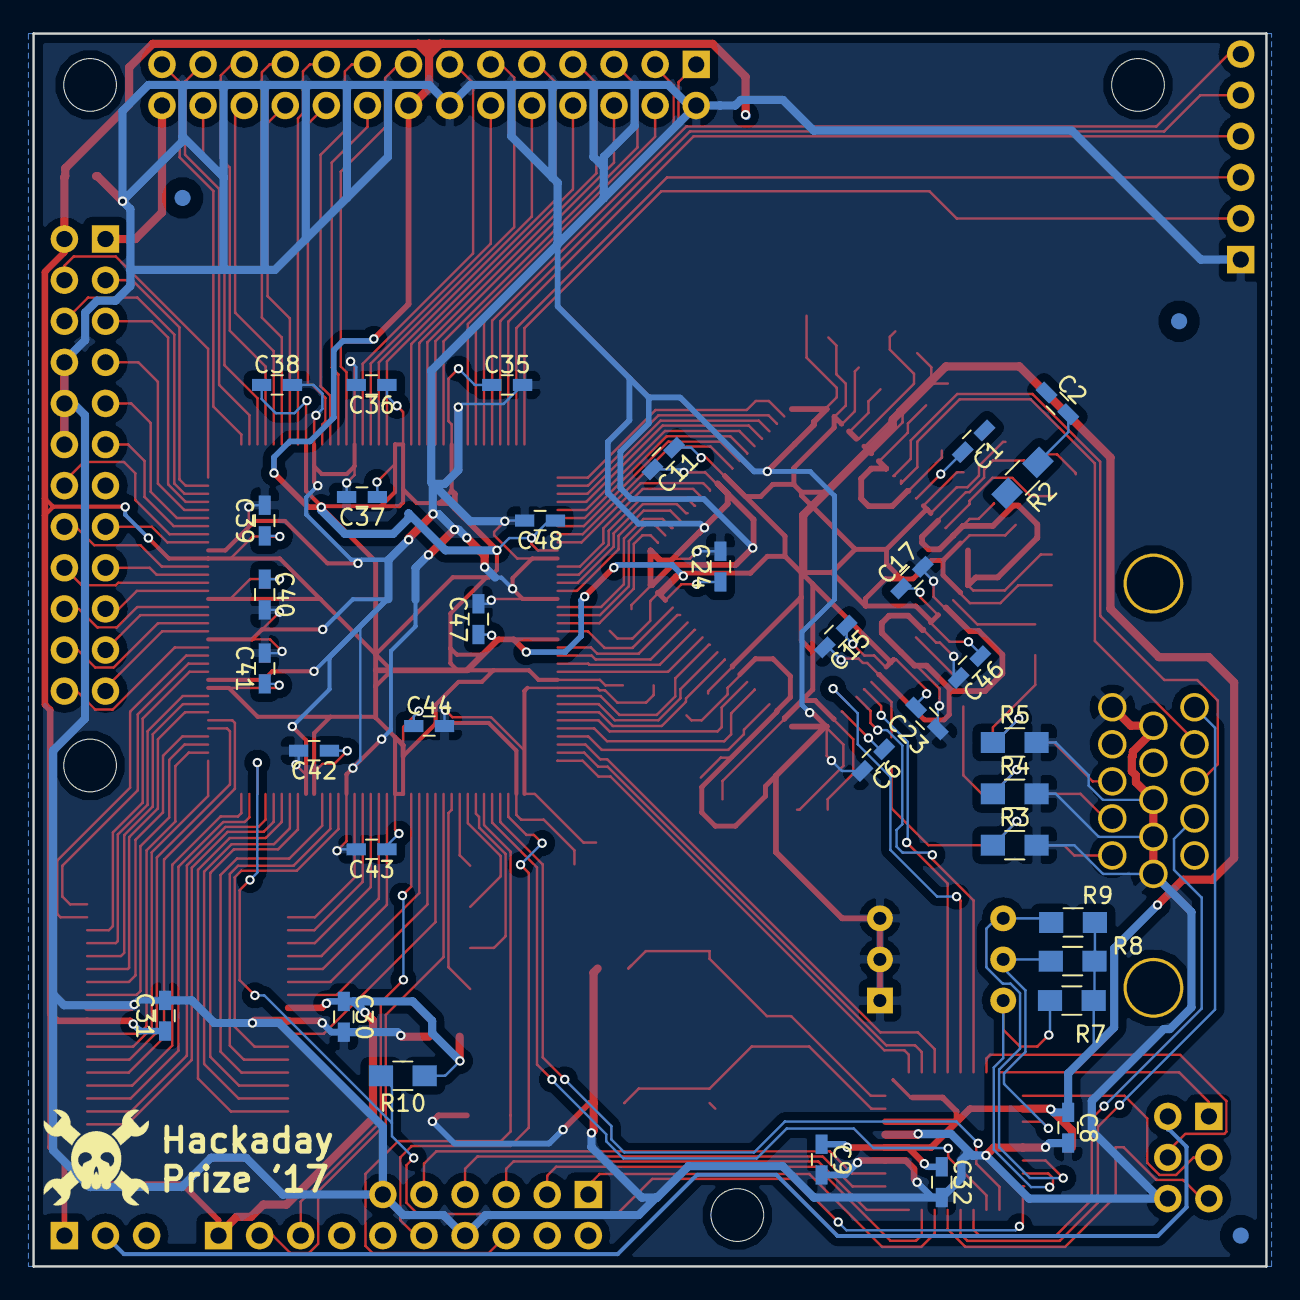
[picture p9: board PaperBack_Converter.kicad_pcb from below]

Board: 2 copper layers, 76.2 x 76.2 mm, 79 parts (34 on the bottom side), 156 nets.

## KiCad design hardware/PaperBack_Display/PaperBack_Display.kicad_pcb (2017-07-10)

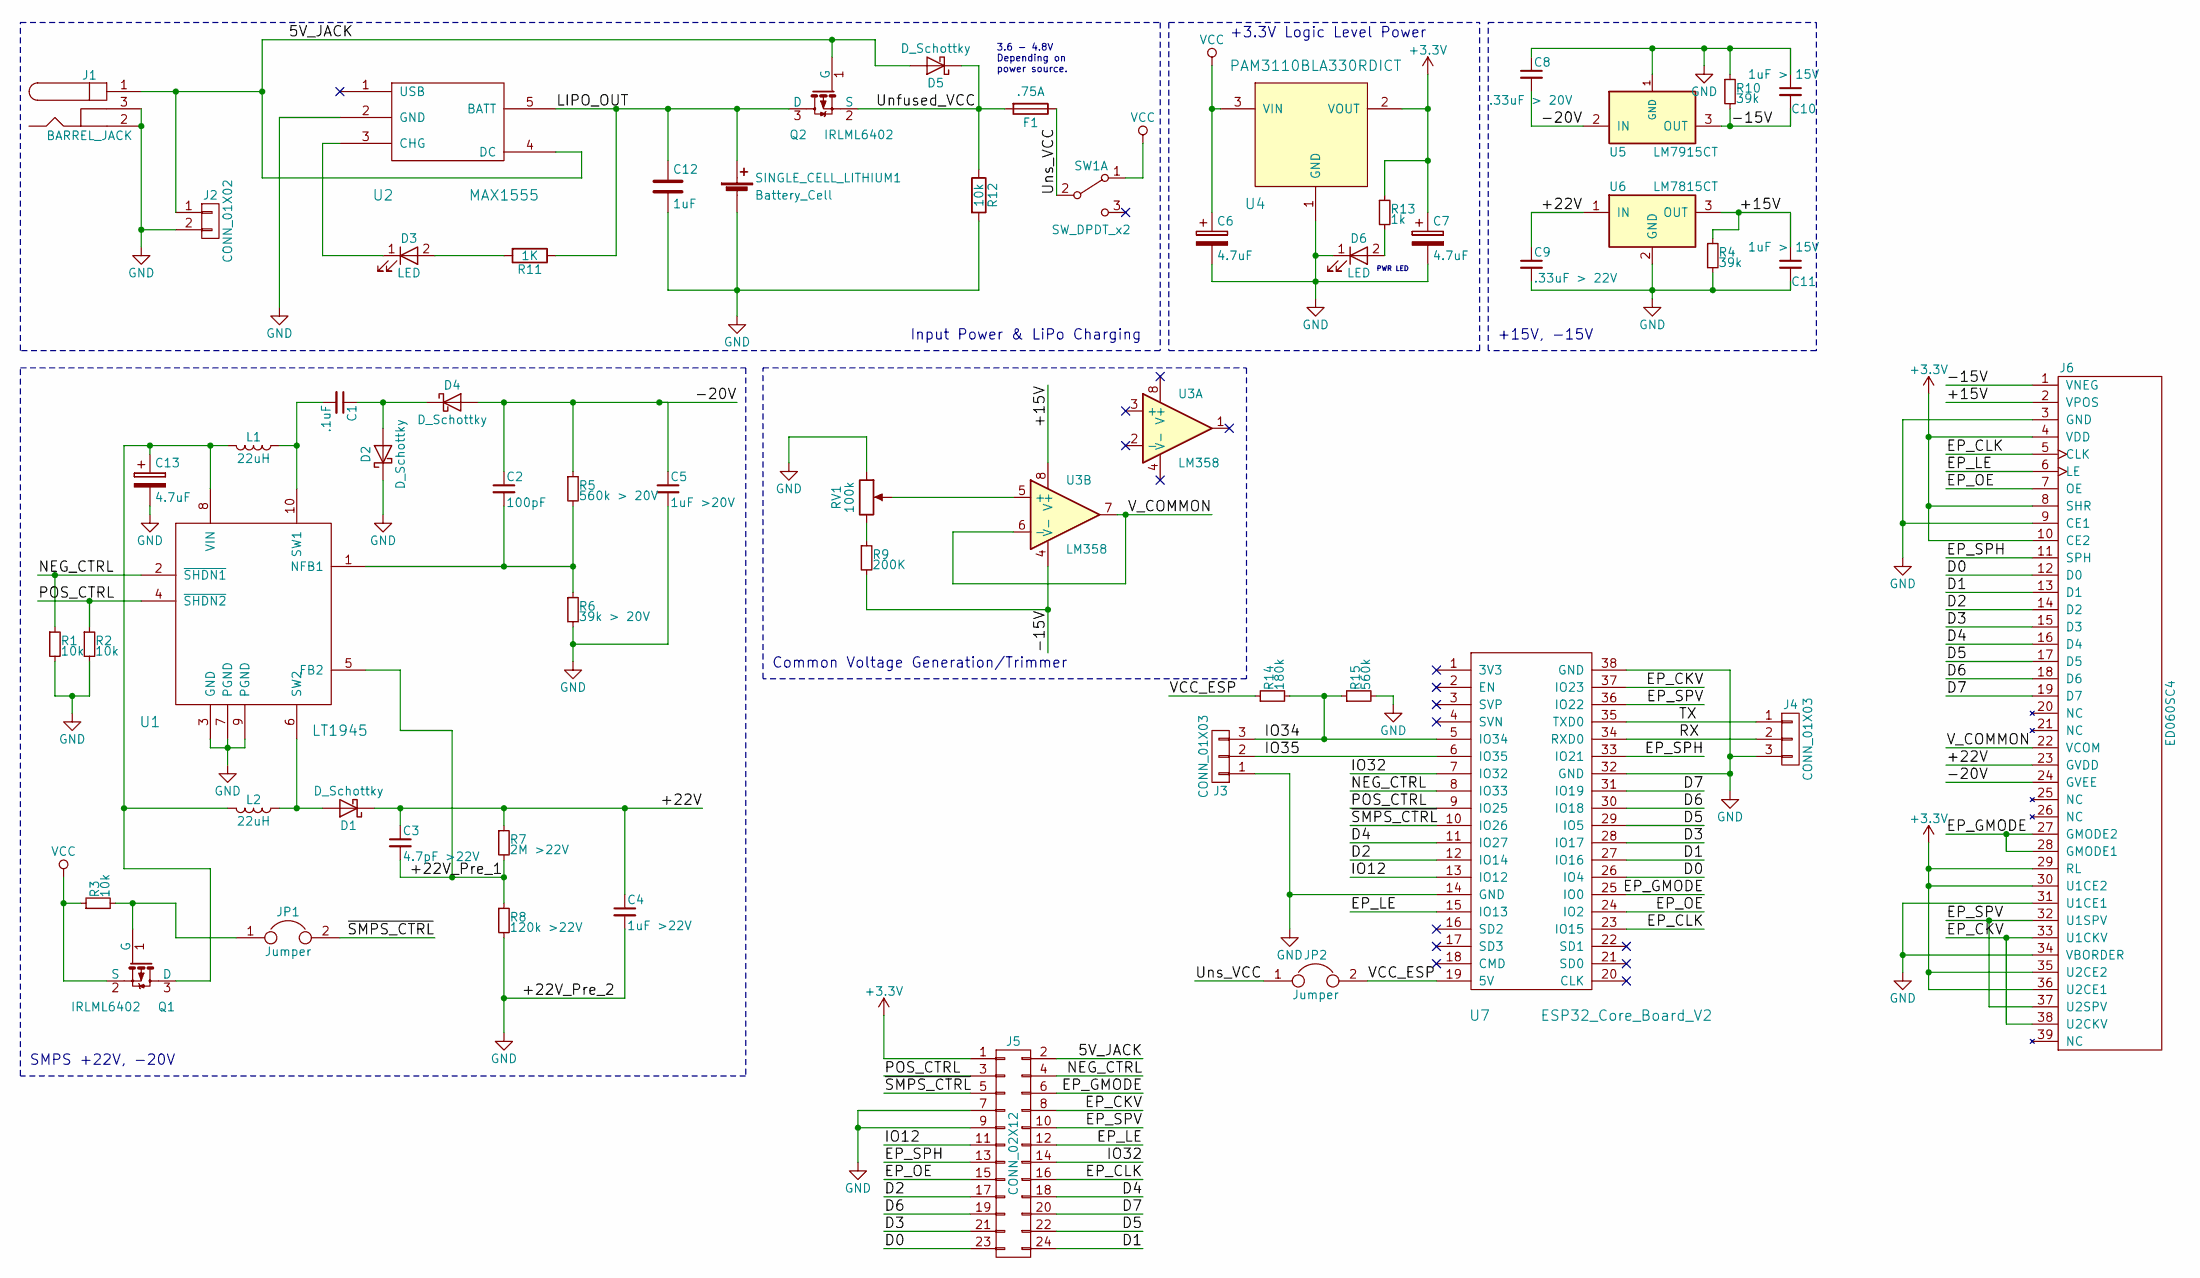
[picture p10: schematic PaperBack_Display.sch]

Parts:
C1: .1uF; C_0603_HandSoldering
C2: 100pF; C_0603_HandSoldering
C3: 4.7pF >22V; C_0603_HandSoldering
C4: 1uF >22V; C_0603_HandSoldering
C5: 1uF >20V; C_0603_HandSoldering
C6, C7, C13: 4.7uF; C_0603_HandSoldering
C8: .33uF > 20V; C_0603_HandSoldering
C9: .33uF > 22V; C_0603_HandSoldering
C10, C11: 1uF > 15V; C_0603_HandSoldering
C12: 1uF; C_0603_HandSoldering
D1, D2, D4, D5: D_Schottky; D_SOD-123F
D3, D6: LED; LED_0805
F1: .75A; R_1210_HandSoldering
J1: BARREL_JACK; Switchcraft_5.5_2.1_Barrel_Jack
J2: CONN_01X02; Pin_Header_Straight_1x02_Pitch2.54mm
J3, J4: CONN_01X03; Pin_Header_Straight_1x03_Pitch2.54mm
J5: CONN_02X12; Pin_Header_Straight_2x12_Pitch2.54mm
J6: ED060SC4
JP1, JP2: Jumper; Pin_Header_Straight_1x02_Pitch2.54mm
L1, L2: 22uH; DG6050C_Murata_Inductor
Q1, Q2: IRLML6402; SOT-23
R1, R2, R3, R12: 10k; R_0805_HandSoldering
R4, R10: 39k; R_0805_HandSoldering
R5: 560k > 20V; R_0805_HandSoldering
R6: 39k > 20V; R_0805_HandSoldering
R7: 2M >22V; R_0805_HandSoldering
R8: 120k >22V; R_0805_HandSoldering
R9: 200K; R_0805_HandSoldering
R11: 1K; R_0805_HandSoldering
R13: 1k; R_0805_HandSoldering
R14: 180k; R_0805_HandSoldering
R15: 560k; R_0805_HandSoldering
RV1: 100k; CB10V_Trimmer
SINGLE_CELL_LITHIUM1: Battery_Cell; JST_Right_Angle_02x01
SW1: SW_DPDT_x2; Pin_Header_Straight_1x03_Pitch2.54mm
U1: LT1945; MSOP-10_3x3mm_Pitch0.5mm
U2: MAX1555; SOT-23-5_HandSoldering
U3: LM358; DIP-8_W7.62mm
U4: PAM3110BLA330RDICT; TO-252-3_TabPin2
U5: LM7915CT; TO-252-3_TabPin2
U6: LM7815CT; TO-252-3_TabPin2
U7: ESP32_Core_Board_V2; ESP32_Core_Board_v2

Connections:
+3V3: C7.1, J5.1, J6.4 (VDD), J6.8 (SHR), J6.10 (CE2), J6.29 (RL), J6.30 (U1CE2), J6.35 (U2CE2), J6.36 (U2CE1), R13.1, U4.2 (VOUT)
/5V_JACK: D5.2 (A), J1.1, J2.1, J5.2, Q2.1 (G), U2.4 (DC)
/+15V: C11.1, J6.2 (VPOS), R4.1, U3.8 (V+), U6.3 (OUT)
/+22V: C3.1, C4.1, C9.1, D1.1 (K), J6.23 (GVDD), R7.1, U6.1 (IN)
/+22V_Pre_1: C3.2, R7.2, R8.1, U1.5 (FB2)
/-15V: C10.2, J6.1 (VNEG), R9.2, R10.2, U3.4 (V-), U5.3 (OUT)
/-20V: C2.1, C5.1, C8.2, D4.2 (A), J6.24 (GVEE), R5.1, U5.2 (IN)
/D0: J5.23, J6.12 (D0), U7.26 (IO4)
/D1: J5.24, J6.13 (D1), U7.27 (IO16)
/D2: J5.17, J6.14 (D2), U7.12 (IO14)
/D3: J5.21, J6.15 (D3), U7.28 (IO17)
/D4: J5.18, J6.16 (D4), U7.11 (IO27)
/D5: J5.22, J6.17 (D5), U7.29 (IO5)
/D6: J5.19, J6.18 (D6), U7.30 (IO18)
/D7: J5.20, J6.19 (D7), U7.31 (IO19)
/EP_CKV: J5.8, J6.33 (U1CKV), J6.38 (U2CKV), U7.37 (IO23)
/EP_CLK: J5.16, J6.5 (CLK), U7.23 (IO15)
/EP_GMODE: J5.6, J6.27 (GMODE2), J6.28 (GMODE1), U7.25 (IO0)
/EP_LE: J5.12, J6.6 (LE), U7.15 (IO13)
/EP_OE: J5.15, J6.7 (OE), U7.24 (IO2)
/EP_SPH: J5.13, J6.11 (SPH), U7.33 (IO21)
/EP_SPV: J5.10, J6.32 (U1SPV), J6.37 (U2SPV), U7.36 (IO22)
/IO12: J5.11, U7.13 (IO12)
/IO32: J5.14, U7.7 (IO32)
/IO34: J3.3, R14.2, R15.1, U7.5 (IO34)
/IO35: J3.2, U7.6 (IO35)
/LIPO_OUT: C12.1, Q2.3 (D), R11.1, SINGLE_CELL_LITHIUM1.1 (+), U2.5 (BATT)
/NEG_CTRL: J5.4, R1.1, U1.2 (~SHDN1), U7.8 (IO33)
/POS_CTRL: J5.3, R2.1, U1.4 (~SHDN2), U7.9 (IO25)
/RX: J4.2, U7.34 (RXD0)
/TX: J4.1, U7.35 (TXD0)
/Unfused_VCC: D5.1 (K), F1.2, Q2.2 (S), R12.1
/Uns_VCC: F1.1, JP2.1, SW1.2 (B)
/VCC_ESP: JP2.2, R14.1, U7.19 (5V)
/V_COMMON: J6.22 (VCOM), U3.6 (-), U3.7
/~SMPS_CTRL: J5.5, JP1.2, U7.10 (IO26)
GND: C4.2, C5.2, C6.2, C7.2, C8.1, C9.2, C10.1, C11.2, C12.2, C13.2, D2.1 (K), D6.1 (K), J1.2, J1.3, J2.2, J3.1, J4.3, J5.7, J5.9, J6.3 (GND), J6.9 (CE1), J6.31 (U1CE1), J6.34 (VBORDER), R1.2, R2.2, R4.2, R6.2, R8.2, R10.1, R12.2, R15.2, RV1.1, SINGLE_CELL_LITHIUM1.2 (-), U1.3 (GND), U1.7 (PGND), U1.9 (PGND), U2.2 (GND), U4.1 (GND), U5.1 (GND), U6.2 (GND), U7.14 (GND), U7.32 (GND), U7.38 (GND)
unnamed: C1.1, D2.2 (A), D4.1 (K)
unnamed: C1.2, L1.1, U1.10 (SW1)
unnamed: C2.2, R5.2, R6.1, U1.1 (NFB1)
unnamed: C13.1, L1.2, L2.2, Q1.3 (D), U1.8 (VIN)
unnamed: D1.2 (A), L2.1, U1.6 (SW2)
unnamed: D3.1 (K), U2.3 (CHG)
unnamed: D3.2 (A), R11.2
unnamed: D6.2 (A), R13.2
unnamed: JP1.1, Q1.1 (G), R3.2
unnamed: R9.1, RV1.3
unnamed: RV1.2, U3.5 (+)
VCC: C6.1, Q1.2 (S), R3.1, SW1.1 (A), U4.3 (VIN)

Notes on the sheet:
3.6 - 4.8V Depending on power source.
Input Power & LiPo Charging
+3.3V Logic Level Power
SMPS +22V, -20V
+15V, -15V
Common Voltage Generation/Trimmer
PWR LED

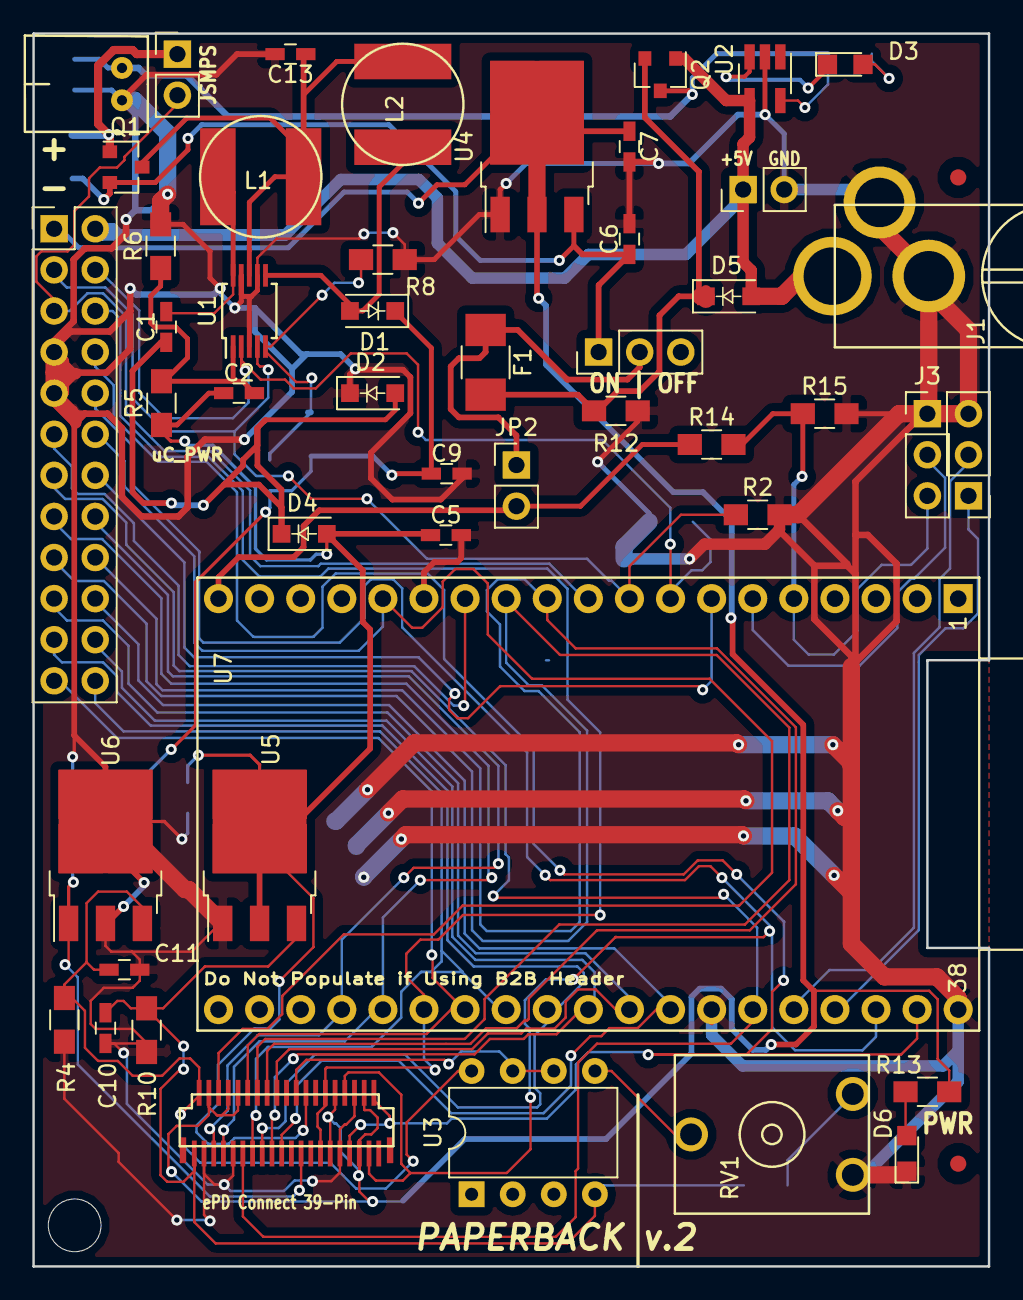
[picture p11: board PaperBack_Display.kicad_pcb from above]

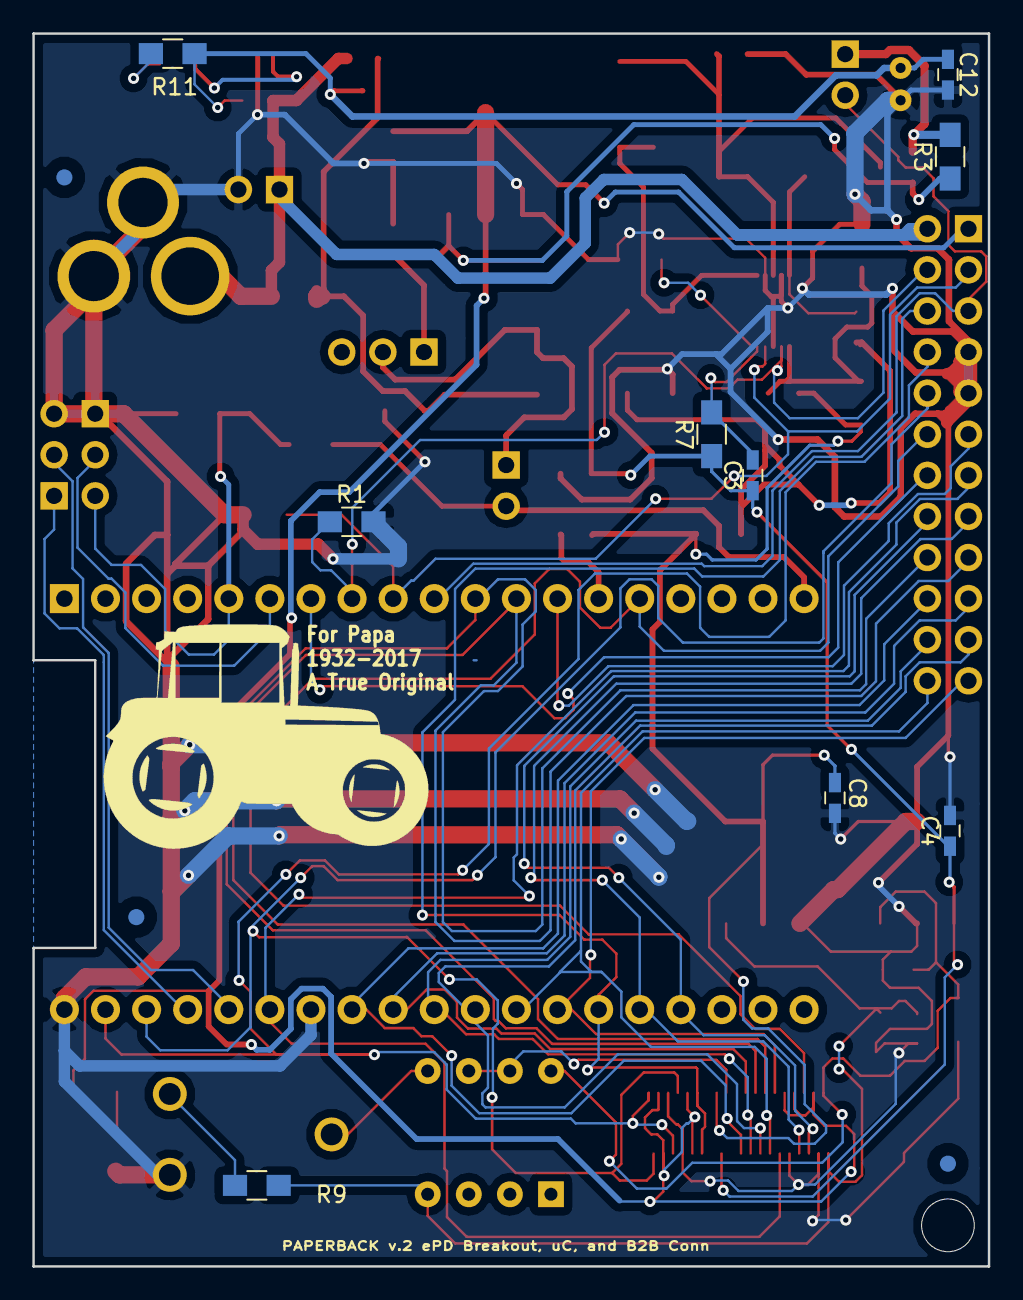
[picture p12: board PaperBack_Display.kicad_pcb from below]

Board: 2 copper layers, 59.1 x 76.2 mm, 57 parts (9 on the bottom side), 49 nets.

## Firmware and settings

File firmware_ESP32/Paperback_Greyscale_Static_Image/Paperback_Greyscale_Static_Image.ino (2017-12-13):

/* Simple firmware for a ESP32 displaying a static image on an EPaper Screen.
 *
 * Write an image into a header file using a 3...2...1...0 format per pixel,
 * for 4 bits color (16 colors - well, greys.) MSB first.  At 80 MHz, screen
 * clears execute in 1.075 seconds and images are drawn in 1.531 seconds.
 */
#include "image.hpp"
//#include "beat.hpp"
#include "Paperback.hpp"

/* Screen Constants */
#define EPD_WIDTH     800
#define EPD_HEIGHT    600
#define CLK_DELAY_US  0
#define VCLK_DELAY_US 0
#define OUTPUT_TIME   2
#define CLEAR_BYTE    0B10101010
#define DARK_BYTE     0B01010101

/* Display State Machine */
enum ScreenState {
        CLEAR_SCREEN = 0,
        DRAW_SCREEN = 1,
};

/* Pointer to the EPaper object */
Paperback *EPD;

/* Contrast cycles in order of contrast (Darkest first).  */
const uint8_t contrast_cycles[] = {2,2,1,1};
const uint8_t sz_contrast_cycles = sizeof(contrast_cycles)/sizeof(uint8_t);

/* Screen clearing state */
const uint8_t clear_cycles[] = {
  CLEAR_BYTE, CLEAR_BYTE, CLEAR_BYTE, CLEAR_BYTE, CLEAR_BYTE,
  CLEAR_BYTE, CLEAR_BYTE, CLEAR_BYTE,
  DARK_BYTE, DARK_BYTE, DARK_BYTE, DARK_BYTE, DARK_BYTE, DARK_BYTE,
  CLEAR_BYTE, CLEAR_BYTE, CLEAR_BYTE, CLEAR_BYTE, CLEAR_BYTE,
  CLEAR_BYTE, CLEAR_BYTE, CLEAR_BYTE,
  CLEAR_BYTE,
};
const uint8_t sz_clear_cycles = sizeof(clear_cycles)/sizeof(uint8_t);

/* Setup serial and allocate memory for the Paperback pointer */
void setup()
{
        Serial.begin(115200);
        Serial.println("Blank screen!");

        EPD = new Paperback(
                CLK_DELAY_US,
                VCLK_DELAY_US,
                OUTPUT_TIME
        );
}


/* Setup serial and allocate memory for the Paperback pointer */
void loop()
{
        // Variables to set one time.
        static ScreenState _state = CLEAR_SCREEN;

        delay(300);
        EPD->poweron();

        uint32_t timestamp = 0;
        if (_state == CLEAR_SCREEN) {
                Serial.println("Clear cycle.");
                timestamp = millis();
                EPD->data_output(CLEAR_BYTE);
                for (int k = 0; k < sz_clear_cycles; ++k) {
                        EPD->vscan_start();
                        EPD->data_output(clear_cycles[k]);
                        // Height of the display
                        for (int i = 0; i < EPD_HEIGHT; ++i) {
                                EPD->hscan_start();

                                // Width of the display, 4 Pixels each.
                                for (int j = 0; j < (EPD_WIDTH/4); ++j) {
                                        EPD->clock_pixel();
                                }

                                EPD->hscan_end();
                                EPD->output_row();
                                EPD->latch_row();
                        }

                        EPD->vscan_end();

                } // End loop of Refresh Cycles Size
                _state = DRAW_SCREEN;

        } else if (_state == DRAW_SCREEN) {
                Serial.println("Draw cycle.");
                timestamp = millis();
                for (int k = 0; k < sz_contrast_cycles; ++k) {
                        for (
                            int contrast_cnt = 0;
                            contrast_cnt < contrast_cycles[k];
                            ++contrast_cnt
                        ) {

                                EPD->vscan_start();
                                const uint8_t *dp = img_bytes;

                                // Height of the display
                                for (int i = 0; i < EPD_HEIGHT; ++i) {
                                        EPD->hscan_start();

                                        // Width of the display, 4 Pixels each.
                                        for (
                                            int j = 0;
                                            j < (EPD_WIDTH/4);
                                            ++j
                                        ) {

                                                uint8_t pixel = 0B00000000;
                                                uint8_t pix1 = \
                                                    (*(dp) >> 7 - k) & 1;
                                                uint8_t pix2 = \
                                                    (*(dp++) >> 3 - k) & 1;
                                                uint8_t pix3 = \
                                                    (*(dp) >> 7 - k) & 1;
                                                uint8_t pix4 = \
                                                    (*(dp++) >> 3 - k) & 1;

                                                pixel |= \
                                                    ( EPD->pixel_to_epd_cmd(
                                                        pix1
                                                    ) << 6
                                                );
                                                pixel |=
                                                    ( EPD->pixel_to_epd_cmd(
                                                        pix2
                                                    ) << 4
                                                );
                                                pixel |= \
                                                    ( EPD->pixel_to_epd_cmd(
                                                        pix3
                                                    ) << 2
                                                );
                                                pixel |= \
                                                    ( EPD->pixel_to_epd_cmd(
                                                        pix4
                                                    ) << 0
                                                );

                                                EPD->data_output(pixel);
                                                EPD->clock_pixel();
                                        }

                                        EPD->hscan_end();
                                        EPD->output_row();
                                        EPD->latch_row();
                                }

                                EPD->vscan_end();
                        } // End contrast count

                } // End loop of Refresh Cycles Size

                _state = CLEAR_SCREEN;
        }

        // Print out the benchmark
        timestamp = millis() - timestamp;
        Serial.print("Took ");
        Serial.print(timestamp);
        Serial.println(" ms to redraw the screen.");
        EPD->poweroff();

        // Wait 5 seconds then do it again
        delay(7500);
        Serial.println("Going active again.");
}

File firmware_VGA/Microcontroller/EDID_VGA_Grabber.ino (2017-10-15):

#include "SoftI2CMaster.h"
#include <Wire.h>

// Switch locations (all on Analog)
#define SW1 0     // ADC0
#define SW2 6     // ADC6
#define SW3 7     // ADC7
#define SW1_OUT 5  // PD5
#define SW2_OUT 6  // PD6
#define SW3_OUT 7  // PD7

// Write address for VGA Capture Chip
#define ADDR9883  0B01001100 // When Select pin grounded, this is the address
#define SEL_9883 8 // Select Pin

// Commands in order. See datasheet of AD9883 or MST9883 or similar.
#define I2C_REG1    0x01
#define CMD1        0x42        // 01H: 1056 Pixels wide
#define CMD2        0x00        // 02H: 0
#define CMD3        0B01100000  // 03H: VCO/CP (first 5)
#define CMD4        0B00001111  // 04H: Phase Register
#define CMD5        0x10        // 05H: Clamp placement
#define CMD6        0x36        // 06H: Clamp duration
#define CMD7        0x10        // 07H: HOP Register
#define CMD8        0x80        // 08H: REDGAIN
#define CMD9        0x66        // 09H: GRNGAIN, set to .7V
#define CMD10       0x80        // 0AH: BLUGAIN
#define CMD11       0x80        // 0BH: REDOFFSET
#define CMD12       0x80        // 0CH: GRNOFFSET
#define CMD13       0x80        // 0DH: BLUOFFSET

// Contrast with red
#define RED_OFFSET  0x0B        // Red offset register
#define RED_VAL     0x40        // Lower = brighter

// Power on and off utilities
#define POW_REG     0x0F        // 0FH: Power and status register
#define POW_OFF     0B01001000  // Turn power off
#define POW_ON      0B01001010  // Turn power on

// 800x600 @ 60Hz with a made up model name.
 const byte edid[128] =
{ 0x00, 0xff, 0xff, 0xff, 0xff, 0xff, 0xff, 0x00, 0x41, 0xd0, 0x21, 0x43, 0xc0, 0x09, 0xe7, 0x00,
  0x20, 0x1b, 0x01, 0x03, 0x20, 0x0c, 0x09, 0x00, 0x00, 0x00, 0x00, 0x00, 0x00, 0x00, 0x00, 0x00,
  0x00, 0x00, 0x00, 0xff, 0xc0, 0x00, 0x01, 0x00, 0x01, 0x00, 0x01, 0x00, 0x01, 0x00, 0x01, 0x00,
  0x01, 0x00, 0x01, 0x00, 0x01, 0x00, 0x64, 0x00, 0x00, 0x00, 0x00, 0x00, 0x00, 0x00, 0x00, 0x00,
  0x00, 0x00, 0x00, 0x00, 0x00, 0x00, 0x00, 0x00, 0x00, 0x00, 0x00, 0xff, 0x00, 0x31, 0x35, 0x31,
  0x34, 0x31, 0x33, 0x31, 0x32, 0x0a, 0x20, 0x20, 0x20, 0x20, 0x00, 0x00, 0x00, 0x10, 0x00, 0x00,
  0x00, 0x00, 0x00, 0x00, 0x00, 0x00, 0x00, 0x00, 0x00, 0x00, 0x00, 0x00, 0x00, 0x00, 0x00, 0x00,
  0x00, 0x00, 0x00, 0x00, 0x00, 0x00, 0x00, 0x00, 0x00, 0x00, 0x00, 0x00, 0x00, 0x00, 0x00, 0x17
};

// MiniCore ATMega328p: https://github.com/MCUdude/MiniCore
// Paperback's Conversion board uses SDA for pin 9 and SCL for pin 10
const int sdaPin = 9;
const int sclPin = 10;
SoftI2CMaster i2c = SoftI2CMaster( sclPin, sdaPin, 1 );

// Real Hardware i2C Port
byte data = -1;
const int i2c_port = 0x50; // i2c Port for Monitor EDID

void setup()
{
  /* Generic pin prep */
  pinMode(SEL_9883, OUTPUT);
  digitalWrite(SEL_9883, LOW);

  pinMode(SW1_OUT, OUTPUT);
  pinMode(SW2_OUT, OUTPUT);
  pinMode(SW3_OUT, OUTPUT);

  /* Setup the *9883 with the above commands */
  i2c.beginTransmission(ADDR9883);
  i2c.write(I2C_REG1);
  delay(50);
  i2c.write(CMD1);
  delay(50);
  i2c.write(CMD2);
  delay(50);
  i2c.write(CMD3);
  delay(50);
  i2c.write(CMD4);
  delay(50);
  i2c.write(CMD5);
  delay(50);
  i2c.write(CMD6);
  delay(50);
  i2c.write(CMD7);
  delay(50);
  i2c.write(CMD8);
  delay(50);
  i2c.write(CMD9);
  delay(50);
  i2c.write(CMD10);
  delay(50);
  i2c.write(CMD11);
  delay(50);
  i2c.write(CMD12);
  delay(50);
  i2c.write(CMD13);
  delay(50);
  i2c.endTransmission();

  /* Listen for VGA source asking for capabilities via EDID */
  Wire.begin(i2c_port);
  Wire.onRequest(gotEvent);
  Wire.onReceive(gotData);
}

void powerOn()
{
  i2c.beginTransmission(ADDR9883);
  i2c.write(POW_REG);
  i2c.write(POW_ON);
  i2c.endTransmission();
}

void powerOff()
{
  i2c.beginTransmission(ADDR9883);
  i2c.write(POW_REG);
  i2c.write(POW_OFF);
  i2c.endTransmission();
}

void gotEvent()
{
  Wire.write(edid, 128);
}


void gotData(int byteCount)
{
  while (Wire.available()) {
    data = Wire.read();
  }
}

/*
 *  The loop handles changes in state of the switches. We're not doing
 *  anything too special here such as overloading the behavior to set
 *  things on the uC. It is just forwarding the state to the *_OUT pins
 *  for consumption by the FPGA.
 */
void loop()
{
  float sw1_voltage = analogRead(SW1)*(3.3 / 1023.0);
  float sw2_voltage = analogRead(SW2)*(3.3 / 1023.0);
  float sw3_voltage = analogRead(SW3)*(3.3 / 1023.0);

  if (sw1_voltage < 1.0) {
    digitalWrite(SW1_OUT,LOW);
  } else {
    digitalWrite(SW1_OUT,HIGH);
  }

  if (sw2_voltage < 1.0) {
    digitalWrite(SW2_OUT,LOW);
  } else {
    digitalWrite(SW2_OUT,HIGH);
  }

  if (sw3_voltage < 1.0) {
    digitalWrite(SW3_OUT,LOW);
  } else {
    digitalWrite(SW3_OUT,HIGH);
  }
}

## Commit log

2017-06-11 Initial firmware for ESP32, shows a static image
2017-07-10 Schematic as a PDF
2017-07-10 Firmware update & new PCB image
2017-07-12 Cleaner CSV
    [PaperBack_Display_BOM.csv]
2017-07-23 Update Readme.md
    Update Readme for board 2
2017-07-23 Board 2! Don't build yet, let me be the guinea pig. Will update.
    [PaperBack_Converter.csv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]
2017-07-23 Add schematic
2017-10-08 Adding firmware for second board, UC at first
    [PaperBack_Display.csv]
2017-10-08 VHDL MVP of VGA Display, ~ frame every 5 seconds, can't change it
2017-10-08 Should not have been removed: BOM
    [PaperBack_Display.csv]
2017-10-15 New features with the user switch
